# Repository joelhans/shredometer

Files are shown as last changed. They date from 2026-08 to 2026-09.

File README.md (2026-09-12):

# Shredometer

Arduino Nano Every datalogger for a 9-DOF IMU (LSM9DS1), originally written
by Ryan T Cutshall (last updated 17 Sep 2022) for a classic Nano, and later
tuned on real hardware (see "Firmware changes" below). Logs
accelerometer/magnetometer/gyroscope readings to an SD card at high rate and
displays a rolling "shred score" (peak acceleration in g) on a 7-segment LED
display.

## Hardware

- Arduino Nano Every (ATmega4809 — confirmed via `arduino-cli board list`,
  FQBN `arduino:megaavr:nona4809`). Pin-compatible with the classic Nano,
  but a different chip: more flash and RAM, and a different toolchain/core.
- Adafruit LSM9DS1 9-DOF breakout (I2C)
- microSD card module (SPI)
- Adafruit 0.56" 4-digit 7-segment LED backpack (I2C, address `0x70`)
- Momentary push button

### Wiring

| Signal | Nano Every pin |
|---|---|
| SD card CS | D10 |
| SD card MOSI/MISO/SCK | D11/D12/D13 (hardware SPI) |
| Start button | D2 |
| LSM9DS1 SDA/SCL | A4/A5 (hardware I2C) |
| LED backpack SDA/SCL  | A4/A5 (shared I2C bus) |

The button is read with a plain `INPUT` (not `INPUT_PULLUP`), and the code
waits for the pin to go `HIGH` to start logging — so it must be wired with an
external pull-down resistor to GND, with the button connecting the pin to 5V
when pressed.

## Firmware

Sketch: [`Shredometer_Datalogger/Shredometer_Datalogger.ino`](Shredometer_Datalogger/Shredometer_Datalogger.ino)

### Firmware changes

Tuned after testing on the real board:

- Accelerometer range raised from 4G to 16G. At 4G, hard hits clipped at
  the sensor's own ceiling, which capped the shred score below its real
  value. 16G costs some resolution on smaller movements but stops the
  clipping.
- The LED display shows one decimal place below 10g (e.g. `7.3`). At 10g
  and above, it rounds to a whole number instead (e.g. `12`), since the
  display can't fit both an extra digit and the decimal. Clamped at 99.
- The SD file is opened once at the start of a run and kept open, instead
  of being reopened on every sample. It's flushed to the card every 15
  samples. This, combined with raising the serial baud rate below, took
  the sample rate from about 15 Hz to over 100 Hz.
- Serial baud rate raised from 9600 to 115200. At 9600, printing each
  sample line over serial took about as long as the rest of the loop
  combined, and was the main bottleneck. This was the biggest single
  factor in the sample-rate jump above.
- Fixed a bug where every logged line was followed by a blank line in the
  file, caused by a doubled line ending (`println()` on a string that already
  ended in `\n`). **This fix has never reached the board.** Every log through
  DL_61 still ends its lines with `\n\r\n`, which only the old `println()`
  path produces. DL_51 onward runs at 113-117 Hz, so the keep-file-open and
  115200-baud changes from the same commit *are* running — the flashed build
  sits between those edits and this one. Expect the blank lines to disappear
  on the next upload. (They are harmless either way: the analysis script
  skips blank lines.)
- The accelerometer is oversampled and peak-held between logged rows. See
  "Sensor limits" below for why, and "Log format" for the two columns it
  adds.

### Dependencies

Installed via `arduino-cli`:

- `Adafruit LSM9DS1 Library` (pulls in `Adafruit Unified Sensor`, `Adafruit BusIO`, `Adafruit LIS3MDL`)
- `Adafruit GFX Library`
- `Adafruit LED Backpack Library`
- `SD`

### Build environment setup

```sh
sudo pacman -S arduino-cli   # or install per https://arduino.github.io/arduino-cli/latest/installation/
arduino-cli config init
arduino-cli core update-index
arduino-cli core install arduino:megaavr
arduino-cli lib install "Adafruit LSM9DS1 Library" "Adafruit GFX Library" "Adafruit LED Backpack Library"
```

### Compile

```sh
arduino-cli compile --fqbn arduino:megaavr:nona4809 Shredometer_Datalogger
```

Compiling currently reports ~63% flash and ~24% RAM used, leaving about
4.6 KB free for local variables — comfortable headroom on the Nano Every's
ATmega4809. (An earlier revision of this sketch targeted a classic Nano,
which has a third of the flash and RAM; on that chip the same code left
under 100 bytes free, which is why the resource-tightness warning used to
live here. If you're building for a classic Nano, use `arduino:avr:nano`
and `arduino:avr` instead, and budget for that headroom.)

### Upload

Your serial port permissions need to allow access to the board. On Arch,
that means being in the `uucp` group (elsewhere, often `dialout`):

```sh
sudo usermod -aG uucp $USER   # then log out and back in
```

Plug in the board, find its serial port, then:

```sh
arduino-cli board list                 # find the port, e.g. /dev/ttyACM0
arduino-cli upload -p /dev/ttyACM0 --fqbn arduino:megaavr:nona4809 Shredometer_Datalogger
```

### Monitor

```sh
arduino-cli monitor -p /dev/ttyACM0 -c baudrate=115200
```

## Usage

1. Power on. The LED display cycles `2.2:2.2` → `1.1:1.1` → `0.0:0.0` as the
   IMU and SD card initialize.
2. Once at `0.0:0.0`, press the start button to begin logging.
3. Data is written to the next available `DL_N.TXT` file on the SD card
   (`DL_0.TXT`, `DL_1.TXT`, ...), as CSV with a header row.
4. The display shows `instantaneous shred score : max shred score` (in g),
   updated every 15 samples. Below 10g, each side shows one decimal place
   (e.g. `7.3`). At 10g and above, that side shows a whole number instead
   (e.g. `12`), since the display can't fit both an extra digit and the
   decimal.

## Analyzing logs

`scripts/analyze_log.py` parses a `DL_N.TXT` file and prints summary stats
(sample count, duration, sample rate, peak/mean shred score). It skips rows
damaged by a bad SD write (a run of `0xFF` mid-line) and reports how many it
dropped; `DL_61.TXT` contains one such row.

```sh
python3 -m venv .venv
.venv/bin/pip install -r scripts/requirements.txt
.venv/bin/python scripts/analyze_log.py path/to/DL_0.TXT
```

It can also produce output in two formats:

- `-o plot.png` — a static matplotlib plot of acceleration and shred score.
- `-H report.html` — a self-contained, interactive HTML report (open it in
  any browser, no server needed): acceleration and shred-score charts with
  hover tooltips, drag-to-zoom, a per-axis legend, and a per-minute data
  table. Uses `scripts/report_template.html` as its template.

```sh
.venv/bin/python scripts/analyze_log.py path/to/DL_0.TXT -H report.html
```

Pass `--accel-range` to set where the accelerometer saturates, in g. It
controls the report's clipping detection and the reference line on the
shred-score chart.

The default is `24`, which looks wrong next to the firmware's
`LSM9DS1_ACCELRANGE_16G` but is correct. The LSM9DS1's "±16 g" mode has a
sensitivity of 0.732 mg/LSB, and a full-scale int16 reading of 32767 counts
is therefore 23.99 g, not 16 g. The Adafruit library scales by 9.80665, so
the rail lands at 235.20 m/s², which this script's `G = 9.8` turns into
exactly 24.0000 g. The datasheet's range label and its sensitivity constant
disagree; the sensitivity is what the hardware does. DL_61 confirms it: 61
samples sit on 235.20 m/s² and nothing goes past it.

Use `--accel-range 6` for any log captured before the 16G change (the same
1.5x applies to the "±4 g" setting).

Two things follow from this that are easy to get wrong when reading a report:

- The rail is **per axis**. The shred score is a 3-axis magnitude, so it can
  legitimately reach √3 × 24 = 41.6 g with no axis railing. A shred score
  above 24 g is not by itself evidence of clipping.
- A sample with an axis on the rail was truncated, so its shred score is a
  lower bound, not a measurement. In DL_61 that includes the headline 35.07 g
  peak, and 20 of the top 30 hits.

## Questions to ask and answer

- What's the "correct" ceiling to set? The LSM9DS1 has no range above the
  one we're already using, and DL_61 railed 61 times against DL_55's 2, so
  answering this probably means a different accelerometer. See "Sensor
  limits" below.
- Does not having the Shredometer _firmly_ mounted to the bike have an impact on
  the data? If it's on there really firmly, do we get "cleaner" data?
- Does the starting angle of the Shredometer have any impact on the data? Right
  now it's sitting at an angle because it's attached to the downtube like a
  water bottle might be.
- Does the positioning of the accelerometer on the bike have an impact on the
  data? What if I put it on the rear triangle, which has all the suspension
  motion?
- Do we need any kind of calibration? At the start of a session? Based on
  anything the rider is doing?

## Sensor limits

Two separate ceilings constrain the data, and they are easy to confuse.

### 1. Amplitude: the 24 g per-axis rail

Covered under "Analyzing logs" above. DL_61 railed 61 times; DL_55 railed
twice. The tail of the unrailed distribution falls off by a factor of e
every ~3.5 g, so clearing DL_61 entirely would need roughly
24 + 3.5 x ln(61) = **~38 g**. A ±50 g or ±100 g part would leave margin for
a harder ride. The LSM9DS1 has nothing above the range we already use, so
this means a different accelerometer (the usual shock-logging parts are the
ADXL375 at ±200 g or the H3LIS331DL at ±100/200/400 g).

### 2. Bandwidth: we are aliasing, and this is the bigger problem

The accelerometer's real output data rate is **952 Hz**, with a 408 Hz
anti-aliasing filter. We poll it at 113 Hz. Nyquist is 56.6 Hz, so
everything between 56.6 Hz and 408 Hz folds back down into the measurement.

This is not obvious from the sketch. `setupSensor()` calls
`lsm.setupAccel(lsm.LSM9DS1_ACCELRANGE_16G)` with one argument, and the
library's second parameter defaults to `LSM9DS1_ACCELDATARATE_10HZ` — so the
code appears to ask for 10 Hz. It does not get it. On the LSM9DS1, whenever
the gyroscope is powered on, the accelerometer ODR is dictated by `ODR_G` in
`CTRL_REG1_G` and the `ODR_XL` bits are ignored. `begin()` writes
`CTRL_REG1_G = 0xC0`, which is 952 Hz. The log confirms this: no two
consecutive accelerometer readings in DL_61 are identical, which could not
happen at a 10 Hz ODR polled at 113 Hz.

The aliasing shows up in the spectrum. Accelerometer power does not roll off
toward Nyquist the way a band-limited signal must — the 40-56.6 Hz band still
holds 29% as much power as the entire 0-10 Hz band. That energy is folded in
from above.

The practical consequence: **a recorded peak is not a repeatable measurement
of an impact.** A frame hit rings in the hundreds of Hz. What we log is
whatever the ring happened to be at the instant we polled. Two identical hits
will produce different numbers. Raising the range without fixing this gives
bigger numbers that are still not reproducible.

### What the firmware now does about it (not yet flashed)

The sketch oversamples. `loop()` reads only the accelerometer as fast as the
bus allows, tracks the largest magnitude it sees, and writes a row every
`LOG_INTERVAL_MS` (8 ms, so ~125 Hz). The row carries both the single
instantaneous reading it always did *and* the peak across the burst.

Three supporting changes went with it:

- I2C now runs at 400 kHz instead of 100 kHz, which fits about four times as
  many reads into each window.
- `setupAccel()` states the 952 Hz data rate explicitly. This changes no
  behavior — `ODR_G` already governed it — but the call no longer reads as
  though it asks for 10 Hz.
- The LED display's shred score comes from the burst peak rather than one
  instantaneous sample, so it shows the hardest hit in the window.

### 3. The I2C bus is the real bottleneck (measured on hardware)

An on-board diagnostic settled how much the oversampling actually buys. At the
current 100 kHz bus speed:

| Measurement | Value |
|---|---|
| One `readAccel()` | **946 us** |
| One logged row, no SD write | 6.5 ms |
| One logged row, with SD (from the 113 Hz in real logs) | ~8.8 ms |
| Spare time in an 8 ms window | ~1.5 ms |
| Extra oversampled reads that fit | **1** |

A new sensor sample arrives every 1050 us at 952 Hz, and a single read costs
946 us. **At 100 kHz the bus can barely move one sample in the time the sensor
produces one**, and the per-row work consumes the window on its own. Six bytes
per sample at 952 Hz is 5.7 kB/s, against roughly 5.5 kB/s of usable 100 kHz
I2C throughput. We are at the wire's limit, not the sensor's.

So the oversampling as it stands gains about one extra reading per row. It is
kept because it is correct and becomes valuable the moment the bus is faster,
but it does not fix the peaks by itself.

**400 kHz is not available on this wiring.** It hung the bus on two separate
runs: the first `readAccel()` after `Wire.setClock(400000)` never returns, and
only a power cycle clears it.

The cause is almost certainly the cable to the bar-mounted display. That cable
puts the LED backpack on the far end of roughly a metre of wire, and its
capacitance sits across the same bus the accelerometer uses. Fast mode allows
a 300 ns rise time; with the two breakouts' pull-ups in parallel (about 5k)
the bus does not meet it:

| Bus capacitance | Pull-ups 5k | Pull-ups 2.2k |
|---|---|---|
| 60 pF (bench wiring only) | 254 ns — OK | 112 ns — OK |
| 100 pF (~0.7 m to the bars) | **424 ns — over** | 186 ns — OK |
| 150 pF (~1.2 m to the bars) | **635 ns — over** | 280 ns — OK |

So 400 kHz is not out of reach: it needs 2.2k pull-ups, which is a one-dollar
fix. Note that this stops mattering once the accelerometer moves to SPI, since
the I2C bus would then carry only the display, which updates a few times a
second and does not care about bus speed.
The sketch no longer sets 400 kHz.

Note that a wedged bus *can* be cleared in software, without a power cycle:
clock SCL up to 16 times until the stuck slave releases SDA, then issue a
manual STOP. The diagnostic does this at startup and recovers reliably. Worth
adding to the datalogger if the bus ever wedges during a ride.

**What this means for the FIFO.** Draining 32 FIFO samples is 192 bytes, which
at 100 kHz takes about 17 ms — longer than the logging window it is meant to
fill. The FIFO does not help until the bus is faster. Raising the bus speed
(or moving the accelerometer to SPI) comes first; the FIFO comes after.

Do all of this before buying a new accelerometer. It is the cheap experiment,
and it sizes the amplitude problem properly: with a real peak-hold the 24 g
rail will be hit far more often than 61 times, which is what tells us how
much range we actually need.

## Log format

Rows are CSV with a header. The first ten columns are unchanged from earlier
logs, so old files and new ones parse the same way:

| Column | Meaning |
|---|---|
| `Time Elapsed (ms)` | milliseconds since logging started |
| `Accel X/Y/Z (m/s^2)` | one instantaneous reading, as before |
| `Mag X/Y/Z (uT)` | magnetometer |
| `Gyro X/Y/Z (rad/s)` | gyroscope |
| `Peak \|a\| (m/s^2)` | **new** — largest acceleration magnitude across every oversampled read since the previous row |
| `Burst Samples` | **new** — how many reads that peak covers |

Keep the instantaneous columns for anything distributional: means, spectra,
and orientation all stay valid, and they stay comparable with DL_46 through
DL_61. Use `Peak |a|` for anything about impacts.

`scripts/analyze_log.py` does not read the two new columns yet. It still
computes the shred score from the instantaneous accelerometer columns, so it
runs unchanged on both old and new logs. Switching the shred score over to
`Peak |a|` is a small change, but it would make new reports incomparable with
the existing ones, so it should wait until there is a log to test it against.

## Mk2

The next version replaces the Nano Every and the LSM9DS1 with a XIAO
nRF52840 Sense and an ADXL375 (±200 g, SPI), logs binary at 1 kHz, and puts
the electronics in a printed case that bolts straight to the bottle bosses.
The staged plan, bill of materials, vendor list, and open decisions are in
[docs/mk2.md](docs/mk2.md). Parts are ordered as of 2026-09-07.

## To build

- A snap-in cage that mounts to standard water bottle mounts. The current
  attempt is `hardware/bottle_cage_mount.scad` (v2 cradle, unproven on a
  print). Mk2 replaces it with a case that is its own mount; see
  [docs/mk2.md](docs/mk2.md).
- A handlebar mount for the screen.

## To do

- **Teach `analyze_log.py` about `Peak |a|`.** The firmware now logs a
  peak-held magnitude per row (see "Log format"), and the script still
  ignores it: the shred score comes from the instantaneous accelerometer
  columns. Switching over would make peaks meaningful, but it also makes new
  reports incomparable with DL_46 through DL_61, so it needs a deliberate
  choice: either a `--peak` flag, or report both series side by side. Wait
  for a log that actually has the column before doing it.
- **Get the accelerometer off the shared 100 kHz I2C bus.** This is the
  binding constraint on data quality (see "Sensor limits"). Either fix the
  pull-ups so 400 kHz is stable, or put the accelerometer on SPI. The FIFO
  and any higher-range sensor both depend on this being solved first.
- **Uploads need `pyserial`, not `arduino-cli monitor`.** Reading this board's
  serial output requires DTR asserted. `arduino-cli monitor` and `cat
  /dev/ttyACM0` both return nothing; a short pyserial script works. Note also
  that `avrdude` prints `jtagmkII_initialize(): Cannot locate "flash" and
  "boot" memories in description` on every upload. It is harmless — the flash
  write completes and reports its byte count.

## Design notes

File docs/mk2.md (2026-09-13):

# Shredometer Mk2

A staged plan for rebuilding the logger around a sensor that can see the
real hits, on a bus fast enough to carry them, in a case that is its own
bottle mount.

Written 2026-08-30 from DL_55, DL_61, and on-board timing. Originally a
Claude artifact:
https://claude.ai/code/artifact/996e3555-30bf-40b6-853d-b44880566f15.
This file is the copy of record. Update it here.

Status (2026-09-13): all Phase 2 parts are on hand and wired up through
the display; the bench log in [mk2_build.md](mk2_build.md) has every
result. The logger firmware is written: `Shredometer_Mk2/`, plus
`scripts/mk2_to_csv.py` to convert its binary log into the CSV the
existing analysis reads. The bring-up sketch stays in
`Shredometer_Mk2_Bringup/` for wiring a new subsystem. Not yet run on
real hardware end to end (SD write path only exercised via bring-up, not
the logger). The first ride does not need the display: the plan is to
power the logger from the switch alone and mount it on the bike as-is
inside foam packing in the Mk1 box, ahead of the real Mk2 case. No Mk2
CAD yet; `hardware/` still holds the v2 cradle for the current enclosure,
which Mk2 replaces.

## Why a rebuild, not a part swap

Three ceilings, and they are coupled:

1. **Amplitude.** The LSM9DS1 rails at 24 g. DL_61 hit that 61 times, and
   20 of its top 30 hits are floors, not measurements. The LSM9DS1 has no
   higher range.
2. **Bus.** One `readAccel()` costs 946 µs on the 100 kHz I2C bus. A new
   sample arrives every 1050 µs. 400 kHz wedges the bus, almost certainly
   because of the cable to the bar display (see "Sensor limits" in the
   README).
3. **Bandwidth.** Logging at 113 Hz against a 408 Hz sensor bandwidth
   aliases ring-down into the data. Peaks are not repeatable.

A bigger sensor on the same bus gives the same aliasing at coarser
resolution. The size problem is downstream of this: the enclosure is
99 x 55 x 43 mm because it houses a Nano Every plus three breakouts and
their wiring. The electronics want about 40 x 25 mm.

The mount is the other reason. The v1 cradle failed on its first ride, and
v2 is four printed parts, eight screws, and four foam pads whose only job is
to grip a box that was never designed to be gripped. If the case is the
mount, none of that has to exist.

## Phases

Each phase is useful on its own. Do them in order: each answers a question
the next depends on.

### Phase 1: prove the sensor

Wire an ADXL375 breakout to the existing Nano Every over SPI, alongside the
existing hardware. Ride once. Look at the peaks.

- **Answers:** how hard the bike actually hits. The 38 g figure in the
  README is an extrapolation from clipped, aliased data.
- **Why SPI:** the I2C bus is saturated. The SD card is already on SPI; the
  ADXL375 needs only its own chip-select pin.
- **Also try:** 2.2k pull-ups on SDA and SCL, then retry 400 kHz. The two
  breakouts' pull-ups in parallel are about 5k, which across a metre of
  cable gives roughly a 424 ns rise time. Fast mode allows 300 ns. At 2.2k
  the bus lands near 186 ns.
- **If you stop here:** you know the range to specify, and you have a
  working high-g logger in the old box.

### Phase 2: prove the architecture

Replace the Nano Every with a XIAO nRF52840 Sense, switch the log format
from CSV to binary, and target 1 kHz logging. Confirm the rate with the
burst counter already in the firmware. The display stays wired as it is.

- **Why nRF52840, not RP2040:** wireless is planned for Phase 3, so pick
  the radio-capable part now and port the firmware once. 64 MHz over SPI
  covers 1 kHz logging with room to spare. It also has onboard LiPo
  charging.
- **Why Sense:** the Sense variant has a 6-axis IMU onboard, which covers
  the gyro at no extra part. No magnetometer, which nothing uses.
- **Why binary:** a CSV row is about 65 bytes. Three `int16` values plus a
  timestamp is 8 to 10. Eight times the rate for the same file size.
- **Proves:** that aliasing is gone. Sample above about 800 Hz and the
  folding stops.
- **Bench build:** hand-wired on a 5 x 7 cm FR4 protoboard. Its layout sets
  the post positions and cavity for the Phase 4 case, so build this before
  designing the case.
- **If you stop here:** the data is valid. Correct amplitude, no aliasing.
  Everything after is size and convenience.

### Phase 3: carrier PCB and the radio link

A small board (about 40 x 25 mm) with footprints for the breakouts, not
bare chips. KiCad, JLCPCB or PCBWay or OSH Park, order five.

- **Cutting the cable means a second device.** The bar end needs its own
  MCU, cell, charging, enclosure, firmware, and a reconnect story. That is
  the real cost of wireless, not the radio.
- **Sequence:** logger board first. Leave the bar end as a hand-wired plain
  XIAO nRF52840 plus the existing HT16K33 display for a while.
- **Why BLE:** it is what the nRF52840 is built for, and a phone can talk
  to the logger too.

### Phase 4: case as mount

One printed body with the bottle-boss bolt pattern through it, and a
bolt-on lid. The spine, both collars, the separate lid, and the foam pads
stop existing.

- **Governing constraint:** 64 mm bolt spacing. The body spans both bosses,
  so it lands near 85 mm long. Target about 85 x 35 x 20 mm, one body plus
  one lid, about 60 cm³ against the current 234 cm³.
- **Carries over from `hardware/bottle_cage_mount.scad`:** the M5
  counterbore geometry, the captive M3 nut scheme for the lid, and the
  print-orientation and volume-intersection checks.
- **Structure:** boards on printed posts inside a rigid body. No sliding
  fit, no `FIT_CLEARANCE`, no foam. Foam was a mechanical filter with an
  uncharacterised transfer function, so removing it also removes an
  unknown from the data.
- **Bolt heads:** recess both M5 heads into the floor inside the body. Bolt
  the empty body to the frame, fit the electronics, close the lid.
- **Sealing:** a gasket (silicone sheet or O-ring cord, 1 to 2 mm) at the
  lid. Readout over USB-C, so the bottom face is solid and there is no SD
  hatch facing road spray.
- **Cable exit:** the display is wired until Phase 3, so the body needs one
  sealed exit (4-pin connector or gland) until then. After Phase 3 it has
  none.
- **Fasteners:** two M5 bottle bolts, four M3x10 lid screws with captive
  nuts. Down from twelve.
- **Hard mounting changes the data.** A rigidly mounted sensor sees more
  high-frequency content than the foam-cradled one did. Note the change in
  the log naming so Mk1 and Mk2 rides are not compared blindly.

## Bill of materials

Prices are approximate US retail as of 2026-08-30.

| Part | Why this one | Phase | Qty | ~USD |
|---|---|---|---|---|
| ADXL375 breakout, Adafruit 5374, ±200 g | Purpose-built shock sensor. 3200 Hz output, SPI and I2C. 25.5 x 17.8 mm. Buy genuine: a relabelled ADXL345 gives ±16 g and nothing in the data would tell you. | 1 | 1 | 13 |
| Jumper wires + protoboard, FR4, plated holes, 0.1" pitch | Female-female jumpers plus 28 AWG silicone stranded wire. Assorted pack (2x8 through 5x7 cm); use the 5x7 for Phase 2. Avoid phenolic board. | 1 | 1 | 8 |
| 2.2k resistors | I2C pull-ups, the one-dollar 400 kHz fix. | 1 | 2 | 1 |
| XIAO nRF52840 Sense | 21 x 17.5 mm, BLE, USB-C, onboard 6-axis IMU, LiPo charging, castellated pads. | 2 | 1 | 18 |
| microSD breakout, SPI, 3 V logic | Capacity. Replace with a bare push-push socket on the Phase 3 board. | 2 | 1 | 8 |
| LiPo cell, 500 to 1000 mAh, about 30 x 20 x 6 mm | With protection circuit and JST fitted. Not a bare pouch cell. | 2 | 1 | 9 |
| Tactile button + slide switch | Start and power. Wire the button to `INPUT_PULLUP`; the current external pull-down is unnecessary. | 2 | 2 | 2 |
| Resistors and capacitors: 2.2k, 0.1 µF, 10 µF | Pull-ups and decoupling near every module. | 2 | - | 6 |
| I2C level shifter, BSS138, 4-channel (Adafruit 757) | The bar display runs at 5 V; the XIAO at 3.3 V. Required once the display is on the boost. | 2 | 1 | 4 |
| 5 V boost converter (Adafruit MiniBoost 4654) | Required, not optional: the display's LED current through the XIAO's 3.3 V regulator corrupts the ADXL375 (see the bench log). Runs the display from the battery. | 2 | 1 | 5 |
| 100 µF electrolytic capacitors, 6.3 V or more | One at the backpack's power pins, one at the boost input. | 2 | 2 | 1 |
| Second XIAO nRF52840, plain | The bar end's brain once the cable goes. | 3 | 1 | 16 |
| Second LiPo cell | Bar end. 50 to 90 mA with the display lit, so 500 mAh is several rides. | 3 | 1 | 9 |
| Custom PCB, 5 pcs | Boards are about $5; shipping is most of it. | 3 | 5 | 25 |
| 4-pin connector + cable gland, JST-GH or similar | Only if the case is built before the cable goes. | 4, maybe | 1 | 6 |
| Silicone gasket sheet or O-ring cord, 1 to 2 mm | Seals the lid. | 4 | 1 | 8 |
| M5 bottle bolts + washers | Already measured. | 4 | 2 | 3 |
| M3x10 socket screws + nuts | Same captive-nut scheme as the v2 cradle. Already owned. | 4 | 4 | - |

Totals: Phase 1 about $22. Phases 1 and 2 core parts about $65. All
phases, optionals excluded, about $126.

### Module footprints (datasheet values, unverified with calipers)

| Module | Size |
|---|---|
| XIAO nRF52840 Sense | 21 x 17.5 mm |
| ADXL375 breakout | 25.5 x 17.8 mm |
| microSD breakout | about 25 x 24 mm |
| LiPo | about 30 x 20 x 6 mm |
| 5 x 7 cm protoboard | 50 x 70 mm, about 19 x 27 holes |

Measure every one of these before sizing the Phase 4 case. Do not design
fits from this table.

## Where to buy

Shop by vendor, not by search engine.

| What | Where | Why there |
|---|---|---|
| ADXL375 breakout | Adafruit 5374. Also Pimoroni, Jameco, Digi-Key, Mouser. | Genuine part matters. |
| XIAO nRF52840 Sense | seeedstudio.com direct. Also Amazon, Newegg. | Seeed ships from CN, US, and DE warehouses. Pick the local one. |
| microSD breakout, level shifter, 5 V boost | Adafruit or SparkFun | Documented boards, libraries the examples assume. |
| LiPo cells | Adafruit or SparkFun | Protection circuit and JST fitted. |
| Passives, connectors, exact values | Digi-Key or Mouser | Real stock numbers, no counterfeits. |
| Protoboard, hookup wire, assortments | Amazon | A resistor is a resistor. |
| Soldering iron, multimeter | Amazon, or Pine64 direct for a Pinecil | Buy on reviews. |
| M3 and M5 fasteners, gasket sheet | McMaster-Carr, or Amazon assortments | McMaster tells you exactly what you get. |
| PCB fabrication | JLCPCB, PCBWay, OSH Park | Upload Gerbers from KiCad. |

## Tools

| Item | Needed for | Notes | ~USD |
|---|---|---|---|
| Temperature-controlled soldering iron (e.g. Pinecil) | Phase 2 on | The single most important purchase. | 40 |
| Solder, flux pen, desoldering wick | Phase 2 on | Leaded 63/37 is easier to learn on. Flux matters more than technique. | 20 |
| Multimeter | Phase 1 on | Continuity beeper is 90% of its use. | 25 |
| Flush cutters, tweezers, helping hands | Phase 2 on | The vise matters more than it sounds. | 30 |
| 3D printer | Phase 4 | Already owned. | - |
| KiCad, OpenSCAD, arduino-cli | Phases 3 and 4 | All free. | - |

What is genuinely hard, ranked: PCB design (the only new discipline), the
firmware port to the nRF52840 (moderate: SPI setup and the binary format
are new), soldering castellated modules (easier than it looks with flux),
the enclosure (easiest, the hard constraints are already solved).

Deliberately out of scope: bare surface-mount chips, hot-air rework, paid
assembly. Not worth it until the Phase 3 board works.

## Decisions

- **Display: wired now, BLE at Phase 3.** Decided. Once the accelerometer
  moves to SPI, the I2C bus carries only the display, and a slow bus down a
  long cable is fine for a few updates a second. Test the HT16K33 backpack
  at 3.3 V first. If it is too dim in daylight, add the boost and level
  shifter.
- **Storage: keep microSD, read it over USB-C.** The nRF52840 can present
  the card as a USB drive. No card removal, no hatch. Costs firmware work.
- **Gyro and magnetometer:** the Sense Plus's onboard IMU gives the gyro
  for free, with one catch: its power pin must be driven in high-drive
  mode or the IMU never powers up. See the bench log in
  [mk2_build.md](mk2_build.md). The magnetometer goes away; nothing used
  it.
- **Open:** whether the bar end ever gets its own PCB or stays a hand-wired
  XIAO in a printed box. Live with it before deciding.
- **Open:** the Phase 2 protoboard layout. This gates the Phase 4 case.
- **Open:** peak detection on the ADXL375. At 49 mg per count and 3200 Hz
  bandwidth the resting noise is about 0.2 g rms per axis, so the largest
  of 6300 raw samples a second sits near 2.5 g. The logger cannot report
  raw single-sample peaks. Choose between a lower output data rate (each
  halving cuts noise by about 1.4), a short moving average, or both, and
  verify with a tap test. Also trim the zero-g offset (six-position)
  before trusting anything below a few g.

## Next

1. Parts arrive. Measure every module with calipers and update the
   footprint table above.
2. Phase 1: ADXL375 on the Nano Every over SPI, plus the 2.2k pull-up
   test. One ride.
3. Phase 2: port the firmware to the XIAO, binary log, 1 kHz. Build it on
   the 5 x 7 cm protoboard.
4. Flash `Shredometer_Mk2` to the perfboard XIAO and confirm a full
   power-on-to-power-off log cycle: file created, sectors written, file
   closed cleanly. Pull the card and run `scripts/mk2_to_csv.py` on it.
5. First ride with the perfboard packed in the old enclosure, no display,
   no button: switch on, ride, switch off. This is the check that the
   architecture works end to end before committing to Phase 4 CAD.
6. Phase 4 CAD: a new parametric SCAD file for the body and lid, sized to
   the real protoboard, measured with calipers. Reuse the bolt interface
   and the nut scheme from `hardware/bottle_cage_mount.scad`.

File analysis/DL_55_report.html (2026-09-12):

Shredometer datalogger ·

# Ride Report

Duration

Samples

Peak shred score

Sensor range

## Acceleration

X / Y / Z, in m/s². Band is the range within each window, line is the mean.

X Y Z

Drag on the shred-score chart below to zoom into a time range — both charts stay in sync.

## Shred score

Acceleration magnitude in g. Peak line matches what the onboard display shows; thin line is the window mean.

Peak Mean

Reset zoom

Accel X

Accel Y

Accel Z

Shred peak

Shred mean

Show data table

Time | Samples | Mean accel (m/s²) | Mean shred (g) | Peak shred (g)

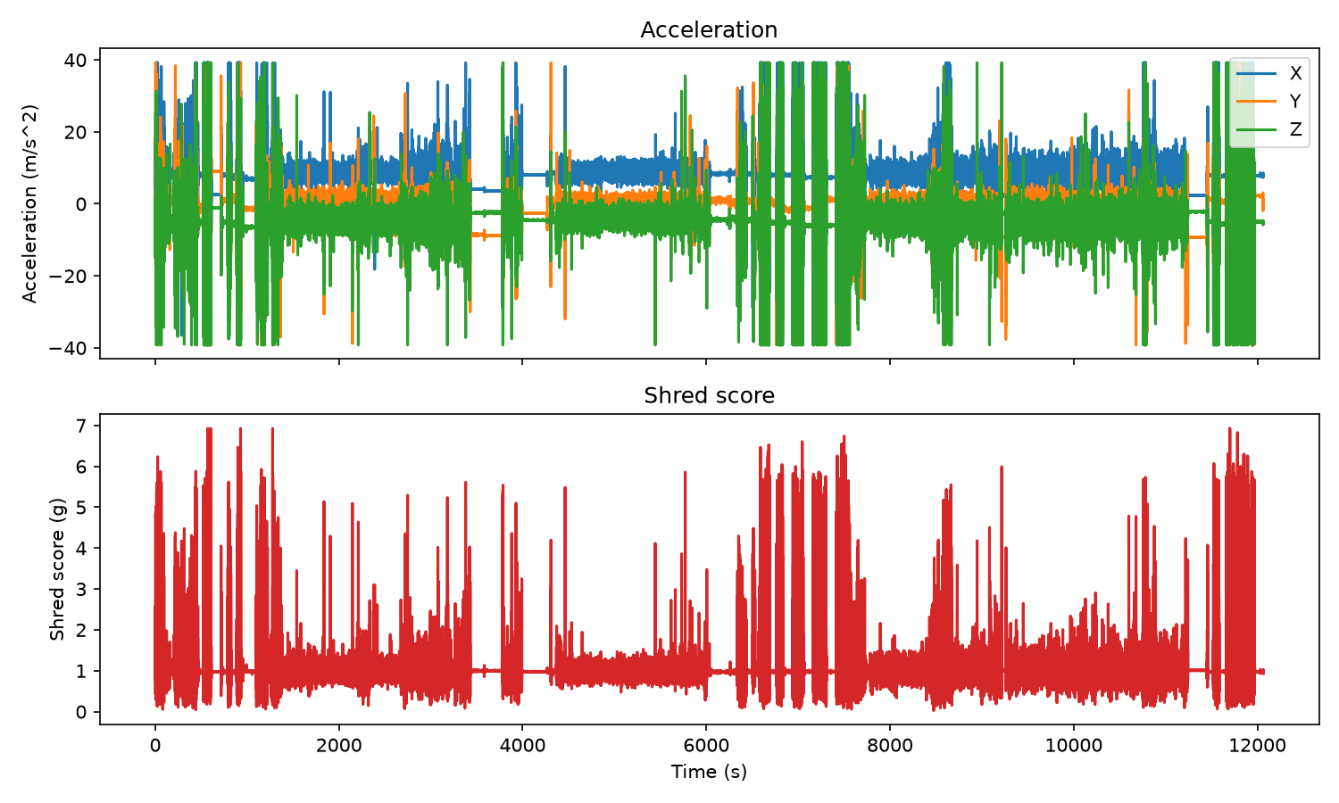
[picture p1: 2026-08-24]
analysis/DL_46_plot.png

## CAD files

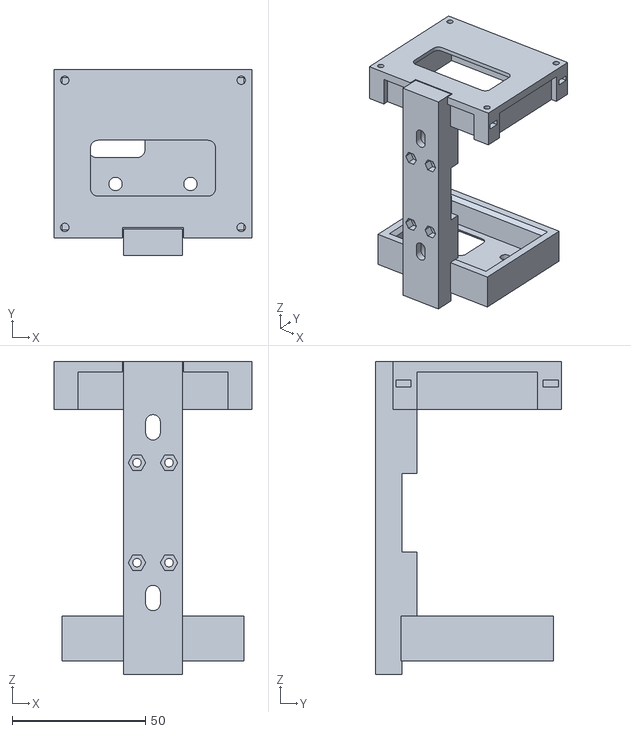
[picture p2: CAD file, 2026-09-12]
hardware/cage_full_REFERENCE_ONLY.stl
74.2 x 69.7 x 117.4

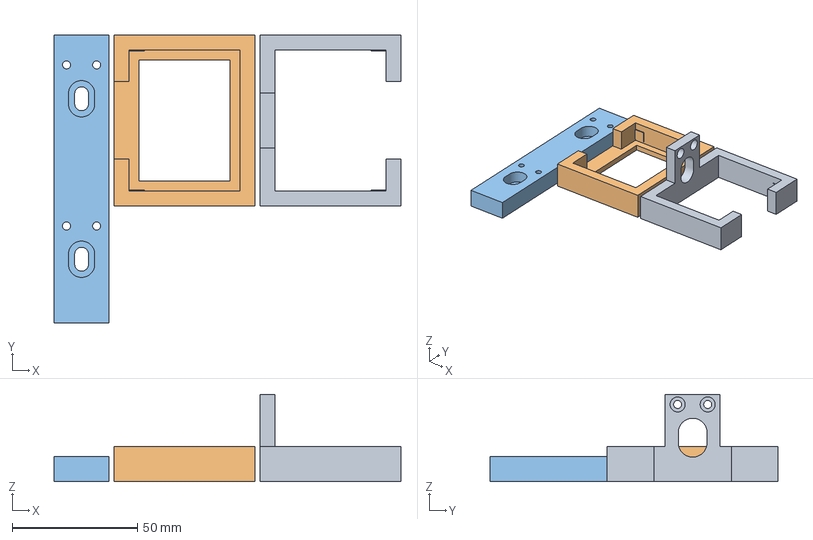
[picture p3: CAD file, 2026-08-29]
hardware/full-print.3mf
138.4 x 115.0 x 34.8 mm
cradle_top_test.stl
cradle_bottom_test.stl
mount_test.stl

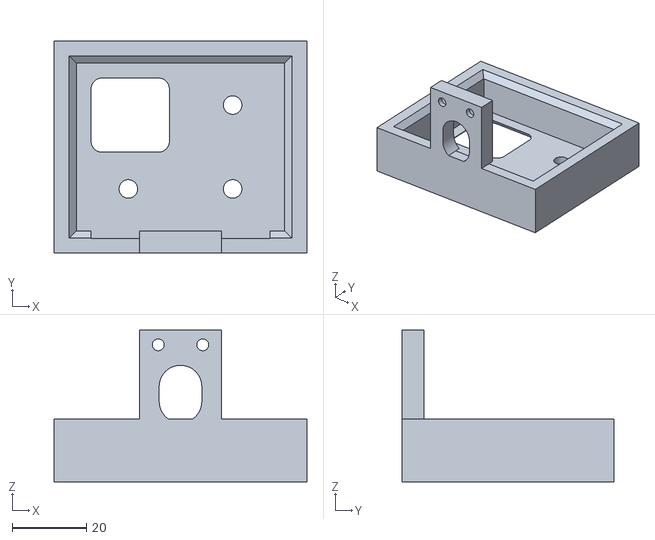
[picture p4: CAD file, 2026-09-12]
hardware/cradle_bottom_test.stl
68.2 x 57.2 x 41.0

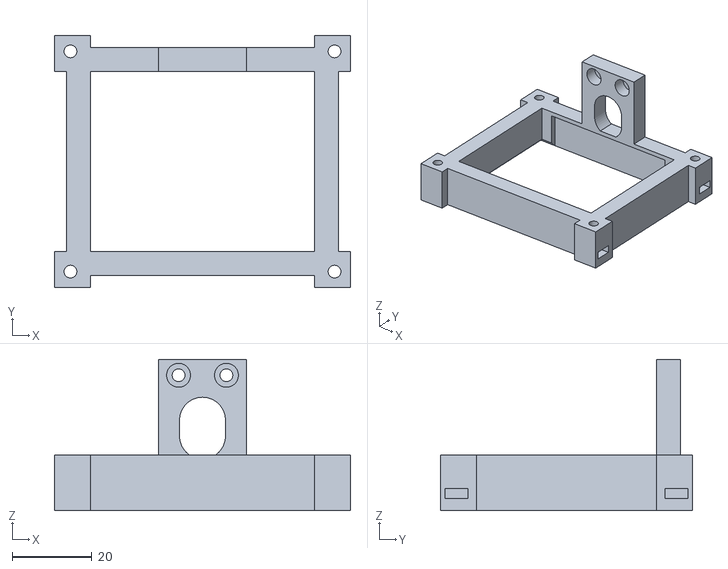
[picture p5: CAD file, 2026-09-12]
hardware/cradle_top_test.stl
74.2 x 63.2 x 38.0

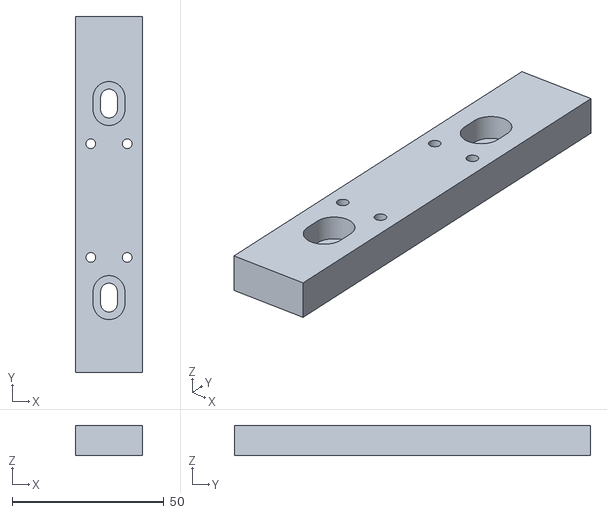
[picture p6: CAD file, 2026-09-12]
hardware/mount_test.stl
22.0 x 117.4 x 10.0

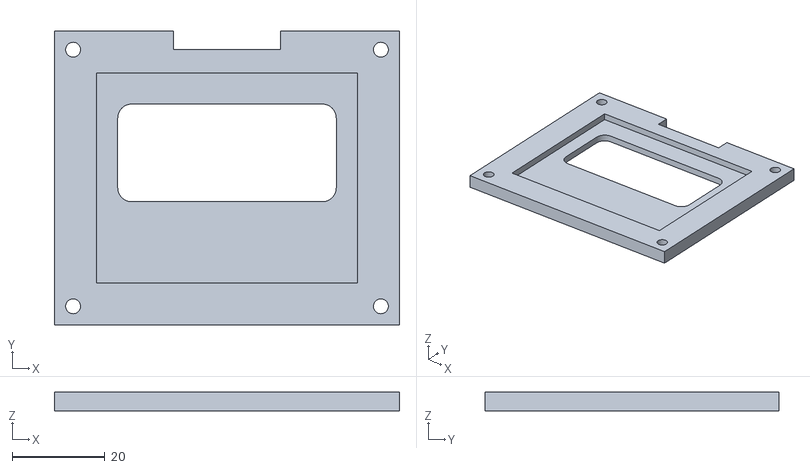
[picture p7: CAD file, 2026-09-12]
hardware/lid_test.stl
74.2 x 63.2 x 4.00

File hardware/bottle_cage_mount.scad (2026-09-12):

// ============================================================
// Shredometer bottle-cage mount + cradle
// ============================================================
// STATUS (2026-09-07): this is the Mk1 cradle, for the bought
// 99 x 55 x 43 mm enclosure. Mk2 replaces the cradle with a printed
// case that is its own bottle mount; see docs/mk2.md. What carries
// over from here: the M5 bolt interface (spine section), the captive
// M3 nut scheme (lid section), and the print-orientation and
// volume-intersection checks described below.
//
// Four printed parts:
//
//   spine         -- baseplate, bolts to the frame's 2-bolt water-
//                    bottle boss.
//   bottom cradle -- a closed collar with a solid floor. The
//                    enclosure stands on a foam pad here.
//   top cradle    -- a closed collar, open at the top.
//   lid           -- a flat plate that bolts onto the top cradle.
//                    This is the "roof": with a foam pad under it,
//                    it traps the enclosure vertically.
//
// The SD card sits on the enclosure's bottom face and has to come out
// after every ride, so the bottom collar's floor opens under the card
// slot. See "SD card access" below. Nothing has to be unbolted to read
// the card, which is also why the lid's screws thread into captive
// nuts rather than into the plastic.
//
// ---------------- What changed after the first ride ----------------
// The first version held the enclosure with friction alone: each
// collar was a "C" with an open front and a small inward pinch, and
// the top collar was open at both ends. On a real ride the enclosure
// worked its way up and out. Three changes fix that:
//
//   1. Both collars are now closed rings. No front opening, no pinch
//      bump, no window through either wall. A closed ring is far
//      stiffer than a "C" and it cannot spread open over a bump.
//   2. The top collar gets a bolt-on lid. The enclosure is now
//      captured between two foam pads (floor and lid) with a fixed
//      amount of crush, so it has nowhere to travel vertically.
//   3. Foam pads take up every remaining gap. See "Foam" below.
//
// A closed 6mm-wall ring cannot be flexed open to admit the
// enclosure, so the enclosure no longer goes in from the front. It
// drops straight down through the top collar into the bottom one,
// and the lid goes on last. Both collars share the same cavity, on
// the same axis, so this is one straight slide.
//
// ---------------- Foam ----------------
// 5mm firm closed-cell sheet, no adhesive backing, so every pad
// needs geometry to hold it in place:
//
//   floor pad -- lies on the bottom collar's solid floor. The cavity
//                walls box it in on all four sides.
//   lid pad   -- sits in a shallow pocket in the lid's underside.
//   back pads -- one per collar, in a shallow pocket milled into the
//                back wall (the spine side). Each pocket is closed at
//                the bottom, so insertion drag pushes the pad down
//                onto a ledge instead of dragging it out.
//
// Cut every pad about 1mm oversize in width and height and press it
// in. The pocket depth means only part of each pad's thickness
// stands proud, which keeps the cradle close to its old size.
//
// Foam only has to sit on one face of an axis to stop a rattle: it
// presses the enclosure against the opposite hard wall, and a
// preloaded contact does not buzz. So the back pads alone handle
// front-to-back. Side to side stays a plain sliding clearance.
//
// ---------------- Assembly order ----------------
// The ring-to-spine screws go in from inside, so they must be driven
// before the enclosure goes in. Both collars now hang off a brace
// that puts its screws in open air between the collars, clear of the
// closed walls, so a driver still reaches them.
//
//   1. Press an M3 nut into each of the four pockets on the spine's
//      back face, and one into each of the top collar's four corner
//      slots.
//   2. Bolt both collars to the spine (M3 cap screws, from inside).
//   3. Bolt the spine to the frame. Both M5 bolts sit between the
//      collars; each brace has a window over its own bolt.
//   4. Press the foam pads in: floor, both back pads, lid.
//   5. Slide the enclosure down through the top collar until it
//      rests on the floor pad.
//   6. Bolt the lid on, into the four corner nuts.
//
// Hardware: 8x M3x10 socket-head cap screws, 8x M3 nuts, plus the two
// M5 bottle-cage bolts. Every screw is the same length on purpose.
//
// ---------------- Print order ----------------
//   RENDER = "mount"         -> the spine, laid on its long face.
//   RENDER = "cradle_bottom" -> the bottom collar, upright.
//   RENDER = "cradle_top"    -> the top collar, upside down.
//   RENDER = "lid"           -> the lid, upside down.
//   RENDER = "full"          -> the whole cage, for preview only.
//
// Print one collar first and check that the enclosure slides through
// it with the back pad in. That is the only fit left to dial in, and
// FIT_CLEARANCE is the knob.

// ---------------- Shredometer enclosure (measured) ----------------
ENCL_LEN   = 99;   // long axis -- mounts vertically, like a bottle
ENCL_DEPTH = 43;   // front-to-back (against the frame)
ENCL_WIDTH = 55;   // side-to-side

// ---------------- Fit ----------------
// Side-to-side only. Front-to-back is set by the back foam pad, and
// vertical by the floor and lid pads, so neither uses this.
// The enclosure now slides the full length of the top collar, so
// this is a sliding clearance, not a press fit -- if it binds,
// raise it; if it rocks side to side, lower it.
FIT_CLEARANCE = 0.6;

// ---------------- Foam ----------------
FOAM_THICK          = 5;   // free thickness of the sheet
FOAM_V_CRUSH        = 0.8; // designed squash per pad, floor and lid.
                            // The lid bottoms out on the collar's top
                            // face, so this is a hard stop: it cannot
                            // be over-tightened, and it does not drift.
FOAM_BACK_CRUSH     = 0.8; // designed squash of each back pad
FOAM_POCKET_DEPTH   = 2;   // how far the back and lid pads sink into
                            // their pockets, so less of the pad stands
                            // proud and the cradle stays compact
FOAM_PAD_SIDE_MARGIN = 4;  // wall left on each side of a back pocket
BACK_PAD_LEDGE      = 1.5; // un-pocketed strip at the bottom of the
                            // top collar's back wall. The pad rests on
                            // it, so sliding the enclosure in cannot
                            // push the pad out the bottom. It sits
                            // flush with the cavity wall, so it never
                            // touches the enclosure.

// ---------------- Cradle collars ----------------
WALL         = 6;   // collar wall thickness -- deep enough to hold the
                     // M3 cap-head counterbore below (see
                     // JOINT_COUNTERBORE_DEPTH) with material behind it
RING_HEIGHT  = 14;  // cavity height of each collar, along the long (Z)
                     // axis. Both collars use the same value.
                     //
                     // Do not raise this much: the two M5 bolt heads
                     // have to stay reachable in the open span between
                     // the collars, and that span is what is left of
                     // the enclosure's length after both collars take
                     // their share. bolt_clearance below echoes how
                     // much room is left -- keep it positive.
RING_MARGIN_BOTTOM = 8; // gap from the cage's bottom to the cavity floor
FLOOR_THICK  = 3;   // solid floor under the bottom collar's cavity.
                     // Solid, not a perimeter lip: the floor foam pad
                     // needs backing across its whole area, or it
                     // dishes into the opening and the clamp goes soft.
DRAIN_DIA    = 5;   // drain holes through that floor -- the collar is
                     // closed all round now, so water needs a way out
ENTRY_CHAMFER = 2;  // lead-in flare at the top of each cavity, so the
                     // enclosure starts square instead of catching on
                     // an edge or peeling a back pad
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

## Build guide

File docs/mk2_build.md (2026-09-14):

# Mk2 build guide

Bench build of the Phase 2 logger on the 5 x 7 cm protoboard. See
[mk2.md](mk2.md) for the plan and the parts list. Phase 1 was skipped: all
the parts arrived together on 2026-09-12, so the ADXL375 goes straight onto
the XIAO.

Parts on hand: XIAO nRF52840 Sense Plus, ADXL375 breakout (Adafruit 5374),
microSD breakout+ (Adafruit 254), LiPo with JST, slide switch, tactile
button, 2.2k resistors, the existing HT16K33 bar display. Not bought: the
5 V boost and the BSS138 level shifter.

## Wiring

All logic is 3.3 V. Every module gets its power from the XIAO's 3V3 pin.

| XIAO pin | nRF52 port | Goes to |
|---|---|---|
| 3V3 | | ADXL375 VIN, microSD **3V** (not 5V, see below), display +, both pull-ups |
| GND | | ADXL375 GND, microSD GND, display - |
| D8 | P1.13 | SCK: ADXL375 SCL and microSD CLK |
| D10 | P1.15 | MOSI: ADXL375 SDA and microSD DI |
| D9 | P1.14 | MISO: ADXL375 SDO and microSD DO |
| D3 | P0.29 | ADXL375 CS |
| D2 | P0.28 | microSD CS |
| D0 | P0.02 | ADXL375 INT1 (data ready; wire it now, the logger uses it later) |
| D4 | P0.04 | SDA: display SDA, with 10k to 3V3 |
| D5 | P0.05 | SCL: display SCL, with 10k to 3V3 |
| D1 | P0.03 | Start button; other side to GND (`INPUT_PULLUP`, pressed = LOW) |
| BAT+ pad | | Slide switch, then LiPo red wire |
| BAT- pad | | LiPo black wire |

The BAT pads are on the underside of the XIAO, next to the USB-C connector.
They are pads, not pins, so the battery wires solder directly to them. Keep
those two leads short and strain-relieve them with a dab of hot glue.

Notes on the choices:

- **microSD power goes to its 3V pin, not its 5V pin.** The 5V pin feeds
  the breakout's regulator. With only 3.3 V in, the regulator sits at its
  dropout, and the card browns out during its own initialization, which is
  its highest-current moment. Symptoms: init errors 0x17 (card stuck in
  idle) or 0x12 (card lost right after reporting ready), while a meter
  still shows 3.3 V at idle. Feeding the 3V pin directly bypasses the
  regulator; Adafruit's forum confirms it as an input on 3.3 V systems.
  Leave the 5V pin empty and never put 5 V on that board.
- **One SPI bus, two devices.** The ADXL375 uses SPI mode 3 and the SD card
  uses mode 0. That is fine: each library sets the mode inside its own
  transaction. What matters is that each device releases MISO when its CS
  is high. The ADXL375 does. The microSD breakout+ has a level-shifter
  buffer on DO for this reason. The bring-up sketch tests it.
- **ADXL375 CS.** The breakout ties CS to 3.3 V through a resistor to
  default to I2C. Driving CS from D3 overrides that. Keep CS high when idle,
  which the sketch does.
- **Button.** `INPUT_PULLUP`, button to ground. No external resistor. This
  is the opposite polarity from the Mk1 wiring.
- **Switch in the battery line, on one leg only.** LiPo red to the
  switch's middle pin, switch's outer pin to the XIAO's BAT+ pad, LiPo
  black straight to BAT-. The switch never touches GND or the 3V3 rail:
  it is entirely on the raw battery net, which is why it belongs
  physically near the XIAO's BAT pads rather than wherever "a long edge"
  first suggested (see the layout diagram below). With the switch off and
  USB plugged in, the XIAO runs from USB but the cell does not charge.
  Turn the switch on to charge.
- **Charge current.** Default is 50 mA. The sketch drives P0.13 low for
  100 mA, which is 0.2 C for a 500 mAh cell. Do not use 100 mA with a cell
  under 200 mAh.
- **Display voltage.** The HT16K33 datasheet says 4.5 to 5.5 V. The
  backpack usually runs at 3.3 V, dimmer. Its input-high threshold is
  0.7 x VDD, so at 5 V it wants 3.5 V logic and the XIAO gives 3.3 V. Run
  it at 3.3 V for now and judge brightness outdoors. If it is too dim, buy
  the boost converter and the level shifter and run it at 5 V.

## Layout on the protoboard

Physical placement is up to you, but these matter:

1. **The ADXL375 is the reference part.** Solder it flat and square to the
   board edges. Write down which board edge each sensor axis points along,
   because the case design and the analysis both need it. The axis arrows
   are printed on the breakout.
2. **XIAO at one short edge**, USB-C facing out. It must be reachable for
   flashing and for USB readout once the case exists.
3. **microSD at the other short edge**, slot facing out, so a card can go
   in without lifting the board.
4. **Switch close to the XIAO's BAT pads,** since it's wired inline with
   the raw battery leads, not the rail. No button on this build.
5. **LiPo under the board**, held with a foam pad. Do not put it under
   the ADXL375.

Use male headers on every module, solder the headers into the protoboard,
and run the 28 AWG silicone wire on the underside. Solder each end of a
wire before cutting the next one, and check each net with the multimeter's
continuity beeper before applying power.

## Perfboard layout

A to-scale top and bottom view, drawn 2026-09-13:
https://claude.ai/code/artifact/c99e428d-f22b-4eea-8c8c-6359c3312635
It's what caught the switch placement above; use it to dry-fit before
soldering anything new, and correct it (or ask for a redraw) if the real
board disagrees.

## Bench log

**2026-09-12.** XIAO (a Sense Plus) soldered to the perfboard, nothing else
wired. Bring-up sketch flashed and reporting. Results with nothing wired:
ADXL375 fail, microSD fail, display no ACK, button released, battery about
3.7 V with no cell (the charger's open output). All as expected.

**The onboard IMU did not answer, now solved (2026-09-13).** Its internal
I2C bus (P0.07 SDA, P0.27 SCL) read low on both lines, on two different
Sense Plus boards, with the IMU supply pin P1.08 driven high. Seeed's
KiCad source for the Plus shows the IMU and its two 10k bus pull-ups all
fed from P1.08, exactly like the Sense. The cause: in the nRF52's standard
GPIO drive, P1.08 sags under the IMU's load and never reaches a high
level (it reads back low). In high-drive mode (`OUTPUT_H0H1`) it comes up,
and the bus follows within a millisecond. The plain Sense gets away with
standard drive; the Plus does not. Any code that powers this IMU on the
Plus must set the pin to high drive before the library's `begin()`. The
Seeed LSM6DS3 library does not, so it fails on the Plus as shipped. The
bring-up sketch does it. Gyro is back on the table.

**2026-09-12, later.** ADXL375 on female-female jumpers to the XIAO
headers. It answers: ID 0xE5, BW_RATE 0x0F (3200 Hz), DATA_FORMAT 0x0B,
POWER_CTL 0x08. Library path: 138 us per sample, about 6300 reads/s. Burst
path, 3000 samples at rest: mean vector 0.86 g (zero-g offset, per
datasheet), rms 0.16 to 0.19 g per axis (normal noise at 3200 Hz), 7 wild
samples including one all-zero triple. The wild samples are the jumpers,
not the sensor. Next: solder the seven wires, rerun, expect zero outliers.
The logger firmware must drop all-zero samples as a guard regardless.

**2026-09-12, ADXL375 soldered.** Seven wires on the underside. Report:
ID 0xE5, mean vector 0.67 g (x +0.60, y -0.02, z +0.29: zero-g offset,
needs a six-position trim later), rms 0.18 to 0.22 g per axis, minimum
0.10 g, maximum 1.83 g, no all-zero samples. The jumper glitches are gone.
Live resting peak through the library path is about 2.5 g: that is the
noise floor of 6300 raw samples a second at 3200 Hz bandwidth, and the
logger must not report raw single-sample peaks. Lower the bandwidth or
average a few samples, or both.

**2026-09-13, microSD.** Wired per the table, first with power on the
breakout's 5V pin: init failed every time (codes 0x17 and 0x12). Moved
power to the 3V pin: passes. Card 7580 MB FAT32. Write test, 200 x 512 B:
mean 1.8 ms, worst 38 ms. SPI bus sharing passes: the ADXL375 answers
after SD traffic. Onboard IMU passes on this board too with the
high-drive fix. Remaining: display, button, battery.

One trap for anyone probing the MISO line: the ADXL375 breakout has a
10k pull-down on SDO (it sets the I2C address). With nothing driving the
bus, MISO reads low against the MCU's pull-up. That is not a fault, and
it makes "DO stuck low" readings meaningless on this board.

**Logger buffer sizing.** A 38 ms SD stall at 1 kHz and 10 bytes per
sample is 380 bytes. A 4 KB ring buffer covers ten times that. RAM is not
a constraint; the nRF52840 has 256 KB.

**2026-09-13, display.** HT16K33 backpack on D4/D5 with one 10k pull-up
per line to 3V3, powered from 3V3, over the existing bar cable. Passes:
ACK at 0x70, shows 8888, then the live peak. Brightness outdoors not yet
judged; that decides the boost converter and level shifter. Note the
backpack's pins are labelled SDA and SCL, not D and C. Remaining: button,
switch and battery.

**2026-09-13, battery pads unreachable.** The XIAO's BAT pads are on its
underside and the module was already soldered to the perfboard. Fix: the
second XIAO gets its battery leads first, then replaces the first in place
(cut the header pins in the gap, pull the stubs one at a time, drop the
new module into the same holes). The order of work now puts the battery
leads before mounting.

**2026-09-13, display current corrupts the sensor.** With the display
connected and blank: ADXL375 scatter 0.17 g per axis, zero glitches. With
8888 lit: 0.69 g and 341 glitches in 3000, some all-zero samples on the
slower library path. Brightness setting does not help (the backpack dims
by pulse width, so the pulse amplitude is unchanged). A 100 nF at the
sensor's pins removes the all-zero samples only. Cause: the backpack's
multiplexed LED current pulses sag the XIAO's 3.3 V regulator and lift the
shared ground. Fix, ordered: Adafruit MiniBoost 5 V (4654) to run the
display from the battery, Adafruit BSS138 level shifter (757) for the two
I2C lines at 5 V, and 100 µF electrolytics at the backpack and the boost
input. Until then the display is usable for bring-up only, and any sensor
measurement must be taken with the display blank.

Also noted: the ADXL375 is powered through its 3Vo pin, not VIN, which
bypasses the breakout's regulator. It works and stays that way.

## Order of work

Do the steps in this order. Run the bring-up sketch after each step and
read the report. Each subsystem reports on its own, so a half-wired board
gives a half-passing report, which is what you want.

1. **Solder the battery leads to the XIAO's BAT pads FIRST.** The pads
   are on the module's underside. Once the module is on the perfboard they
   cannot be reached. This was learned the hard way on 2026-09-13 and cost
   a module swap. Route the two leads off the USB end.
2. **Solder the headers.** ADXL375, microSD breakout, XIAO. Tin the iron,
   flux the pads, one pin at a time. Check for bridges with the beeper.
3. **Flash the bring-up sketch with nothing wired.** Confirm the toolchain
   and the USB serial link. Expect every test to fail except the onboard
   IMU, the button, and the battery.
4. **Wire power and the ADXL375.** 3V3, GND, SCK, MOSI, MISO, CS, INT1.
   Expect `PASS ADXL375` with ID 0xE5 and about 1.0 g at rest.
5. **Wire the microSD.** Add CLK, DI, DO, CS, and power to its 3V pin.
   Put a formatted FAT32 card in. Expect `PASS microSD`, `PASS microSD write`, and
   `PASS SPI bus sharing`. Note the worst-case write time; it sets the
   logger's buffer size.
6. **Wire the display.** SDA to D4, SCL to D5, + and -, and one 10k
   pull-up from each data line to 3V3. Expect 8888 on the display.
7. **Wire the button.** Expect the live line to flip to PRESSED.
8. **Solder the switch and the battery.** Expect a battery reading between
   3.0 and 4.2 V. Unplug USB and confirm the board runs on the cell.
9. **Measure everything with calipers** and update the footprint table in
   [mk2.md](mk2.md). This unblocks the case design.

## Logger firmware

`Shredometer_Mk2/Shredometer_Mk2.ino` is the real logger, distinct from
the bring-up sketch. Differences from bring-up, and why:

- **ADXL375 FIFO, not single-sample reads.** The chip has a 32-entry FIFO
  in stream mode. The loop drains it as often as it can rather than
  reading one sample at a time, so a slow pass through `loop()` (an SD
  write, say) does not lose samples as long as it is under the FIFO's
  time cushion. At 1600 Hz that cushion is 20 ms; the bring-up write test
  measured a worst case of 38 ms, so overruns are expected under load and
  are counted, not hidden. `BW_RATE` defaults to 1600 Hz rather than
  3200 Hz: half the bandwidth for about 1.4x lower noise, still comfortably
  above anything a bike hit produces, and double the FIFO's time cushion.
- **Binary log, not CSV.** 8 bytes a record instead of about 65 bytes a
  CSV row, so the card and the bus carry far more samples for the same
  I/O cost. `scripts/mk2_to_csv.py` converts a log to the CSV
  `analyze_log.py` already reads, so the existing reports run unchanged.
- **No display, no button.** The first ride does not need either; the
  power switch is the start button. A sector's first record is always a
  time and sequence marker, so gaps and clock drift show up in the file
  itself even with nothing to read it live.
- **Onboard IMU included by default,** with the Sense Plus high-drive fix
  from the bench log baked in, and the "never touch a bus that reads low"
  guard from bring-up.
- **Serial commands are optional, for the bench only:** `i` info, `s`
  stop, `r` start a new file, `d` dump the closed file's raw bytes. None
  of this is needed for a ride; power on to power off is the whole flow.
- **LED as a status light** (the same three pins the mbed core drives
  during `initVariant()`): blue while starting up, off and logging (green
  blinks every 500 ms) once both the ADXL375 and the SD card are up, solid
  red if either is missing so a dead sensor doesn't ride silently.

Not yet run end to end on real hardware: the bring-up sketch proved every
subsystem individually, but the logger's FIFO-draining loop and its file
lifecycle (`preAllocate`, `truncate`, the header sector) have only been
tested against a synthetic binary file, not the perfboard.

To try it: `scripts/flash_xiao.sh Shredometer_Mk2`, let it run a minute
with an SD card in, then `s` to stop and `d` to dump, or pull the card and
run `python3 scripts/mk2_to_csv.py path/to/MK2_000.BIN`. Compare the
reported sample rate and overrun count against the FIFO cushion above.

## Toolchain

Installed on 2026-09-12:

```
arduino-cli config add board_manager.additional_urls https://files.seeedstudio.com/arduino/package_seeeduino_boards_index.json
arduino-cli core update-index
arduino-cli core install Seeeduino:nrf52
arduino-cli lib install "Adafruit ADXL375"
python3 -m venv ~/.local/share/adafruit-nrfutil-venv
~/.local/share/adafruit-nrfutil-venv/bin/pip install adafruit-nrfutil
ln -s ~/.local/share/adafruit-nrfutil-venv/bin/adafruit-nrfutil ~/.local/bin/
```

Use the `Seeeduino:nrf52` core, not the mbed one. It is the Adafruit-derived
core with TinyUSB, which is what USB mass-storage readout will need later.
The core needs `adafruit-nrfutil` on the PATH to build and upload. There is
no pipx on this machine, hence the venv.

Two library traps, both hit on 2026-09-12:

- **Do not install the SdFat library.** The core bundles SdFat 2.2.1, and
  the current library-manager release (2.3.0) fails to compile against this
  core's Print class. If `arduino-cli lib list` shows SdFat, uninstall it.
- **The Seeed LSM6DS3 library needs two things on the Sense Plus.** The
  right board target, so it picks the internal bus (Wire1): this core
  defines `TARGET_SEEED_XIAO_NRF52840_SENSE_PLUS`, so that part is fine.
  And the IMU power pin in high-drive mode, which the library does not do.
  Call `pinMode(PIN_LSM6DS3TR_C_POWER, OUTPUT_H0H1)` and drive it high
  before `begin()`. See the bench log. Also note `Adafruit_TinyUSB.h` must
  be included in any sketch that uses `Serial` but no other core library;
  `Wire.h` or `SPI.h` pull it in, a bare sketch does not link.
- **Never do an address-only I2C probe on this core.** The nRF52 Wire
  driver has no timeouts, and `endTransmission()` with zero data bytes
  waits forever for a start event that never comes. Always write at least
  one byte before `endTransmission()`. An I2C scanner sketch written for
  AVR hangs here for this reason.

**Which board.** The unit on the bench identifies its bootloader over USB
as "XIAO nRF52840 Sense Plus" (vendor 2886, product 0065). The plain Sense
bootloader is product 0045. Check with `lsusb -d 2886:` while the board is
in the bootloader. Build for the board you have. D0 to D10 are the same on
both, but the battery, charger, and IMU pin macros differ.

```
scripts/flash_xiao.sh Shredometer_Mk2_Bringup
```

The script compiles, then flashes the right way for the board's state. If
the board is running an app, it uses `arduino-cli upload`. If the board is
already in its bootloader, it calls `adafruit-nrfutil` directly, because
arduino-cli's 1200-baud port touch breaks a bootloader that is already
waiting and the upload fails with "No data received on serial port".
Set `FQBN=Seeeduino:nrf52:xiaonRF52840Sense` in the environment for a
plain Sense.

The bring-up sketch runs its tests when a host opens the port, not at
boot, so the report is never missed. Send `r` in the monitor to run the
tests again after wiring the next subsystem. No reflash needed.

**Serial monitor.** The XIAO is USB CDC, so any terminal works, unlike the
Nano Every. Start the monitor only after the upload has finished and the
board has come back.

```
arduino-cli board list
arduino-cli monitor -p /dev/ttyACM0 -c baudrate=115200
```

The board disconnects and re-enumerates on every upload and every reset.
A monitor that was open across that event keeps a dead handle and shows
nothing forever, and the board can come back as `/dev/ttyACM1` while the
dead handle holds `/dev/ttyACM0`. If the monitor sits at "Connecting",
press Ctrl-C, run `arduino-cli board list` to find the current port, and
start the monitor again. Never leave a monitor open during an upload: it
can also wedge the bootloader's DFU session, which then needs a USB
unplug and replug to recover.

If the upload cannot find the board, double-tap the reset button on the
XIAO. The board enters its bootloader and shows up as a USB drive. Upload
again.

## What the bring-up report should look like

```
Shredometer Mk2 bring-up
------------------------
PASS  ADXL375: ID 0xE5, 30 us per sample, at rest |a| = 1.02 g (expect ~1.0)
PASS  microSD: card 7580 MB, FAT32
PASS  microSD write: 200 x 512 B: mean 900 us, worst 45000 us
PASS  SPI bus sharing: ADXL375 still answers after SD use
PASS  LSM6DS3 (onboard): WHO_AM_I 0x6A (expect 0x6A or 0x69)
PASS  HT16K33 display: ACK at 0x70, showing 8888. Judge brightness at 3.3 V by eye.
PASS  Button: reads released
PASS  Battery: 3.87 V (3.0 empty, 4.2 full; ~0 V means no cell on BAT pads)
```

The timing numbers above are placeholders. Record the real ones here.

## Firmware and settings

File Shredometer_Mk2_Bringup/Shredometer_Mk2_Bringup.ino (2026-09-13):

// Shredometer Mk2 bring-up
// ------------------------
// Tests each subsystem on the XIAO nRF52840 Sense, one at a time, and
// reports PASS or FAIL for each over USB serial. Wire one subsystem,
// flash this, read the report, wire the next. Nothing here logs a
// ride; that is Shredometer_Mk2 (to come).
//
// Board:  Seeed XIAO nRF52840 Sense Plus (bootloader reports USB PID 0x0065)
// FQBN:   Seeeduino:nrf52:xiaonRF52840SensePlus
//         (plain Sense: Seeeduino:nrf52:xiaonRF52840Sense, bootloader PID 0x0045)
// Build:  arduino-cli compile --fqbn Seeeduino:nrf52:xiaonRF52840SensePlus Shredometer_Mk2_Bringup
// Upload: arduino-cli upload -p /dev/ttyACM0 --fqbn Seeeduino:nrf52:xiaonRF52840SensePlus Shredometer_Mk2_Bringup
// D0 to D10 are the same on both boards. The battery, charger, and IMU
// pins come from the variant's macros, so the FQBN must match the board.
//
// See docs/mk2_build.md for the wiring table these pins come from.

#include <SPI.h>
#include <Wire.h>
#include <Adafruit_ADXL375.h>
#include <SdFat.h>
#include <Adafruit_LEDBackpack.h>

// ---------------- Pins (XIAO D numbers) ----------------
// Hardware SPI is fixed: D8 SCK, D9 MISO, D10 MOSI.
// Hardware I2C is fixed: D4 SDA, D5 SCL.
const uint8_t PIN_ADXL_CS   = 3;   // ADXL375 chip select
const uint8_t PIN_ADXL_INT1 = 0;   // ADXL375 INT1 (data ready), optional for bring-up
const uint8_t PIN_SD_CS     = 2;   // microSD chip select
const uint8_t PIN_BUTTON    = 1;   // start button, to GND, INPUT_PULLUP
const uint8_t PIN_HICHG     = PIN_CHARGING_CURRENT;  // P0.13: LOW = 100 mA charge, input = 50 mA

const uint8_t DISPLAY_ADDR  = 0x70;
// 0 to 15. Full brightness with all segments lit pulls well over 100 mA
// in pulses off the shared 3.3 V rail, and the ADXL375 reads that as
// noise on every axis (measured 2026-09-13: 0.5 g rms and bit errors on
// the SPI bus at 15; 0.2 g rms and none with the display unpowered).
const uint8_t DISPLAY_BRIGHTNESS = 4;

// ---------------- Devices ----------------
Adafruit_ADXL375 adxl(PIN_ADXL_CS, &SPI, 12345);
SdFs sd;
Adafruit_7segment display;

bool okAdxl = false, okSd = false, okImu = false, okDisplay = false;
bool displayUp = false;   // display.begin() has run; survives reruns

static void report(const char *name, bool ok, const char *detail = "") {
  Serial.print(ok ? "PASS  " : "FAIL  ");
  Serial.print(name);
  if (detail[0]) { Serial.print(": "); Serial.print(detail); }
  Serial.println();
}

// ---------------- ADXL375 over SPI ----------------
static void testAdxl() {
  char buf[96];
  if (!adxl.begin()) {
    // Say what came back, so a wiring fault can be located.
    //   0x00 every time: MISO stuck low, or the sensor never selected (CS, or no power).
    //   0xFF every time: MISO floating or open (SDO wire), or no power to the sensor.
    //   other, varying:  clock or data wire swapped or open.
    uint8_t ids[4];
    for (int i = 0; i < 4; i++) ids[i] = adxl.getDeviceID();
    pinMode(PIN_SPI_MISO, INPUT_PULLDOWN); delayMicroseconds(200); bool misoDown = digitalRead(PIN_SPI_MISO);
    pinMode(PIN_SPI_MISO, INPUT_PULLUP);   delayMicroseconds(200); bool misoUp   = digitalRead(PIN_SPI_MISO);
    SPI.begin();  // give the pin back to SPI
    snprintf(buf, sizeof buf, "no ID 0xE5. Read %02X %02X %02X %02X. MISO idle: %s",
             ids[0], ids[1], ids[2], ids[3],
             (misoDown != misoUp) ? "floating (SDO wire open, or sensor unpowered)"
                                  : (misoUp ? "driven high" : "driven low"));
    report("ADXL375", false, buf);
    return;
  }
  uint8_t id = adxl.getDeviceID();
  if (id != 0xE5) {
    snprintf(buf, sizeof buf, "device ID 0x%02X, expected 0xE5", id);
    report("ADXL375", false, buf);
    return;
  }
  adxl.setDataRate(ADXL3XX_DATARATE_3200_HZ);

  // Time 1000 raw reads. Each is three 2-byte register reads through
  // the library; the real firmware will do one 6-byte burst instead.
  int16_t x = 0, y = 0, z = 0;
  uint32_t t0 = micros();
  for (int i = 0; i < 1000; i++) { x = adxl.getX(); y = adxl.getY(); z = adxl.getZ(); }
  uint32_t us = (micros() - t0) / 1000;

  float gx = x * 0.049f, gy = y * 0.049f, gz = z * 0.049f;
  float mag = sqrtf(gx * gx + gy * gy + gz * gz);
  snprintf(buf, sizeof buf, "ID 0xE5, %lu us per sample, at rest |a| = %.2f g (expect ~1.0)",
           (unsigned long)us, mag);
  okAdxl = true;
  report("ADXL375", true, buf);
  if (mag < 0.7f || mag > 1.3f) {
    Serial.println("      WARN: |a| at rest is not near 1 g. Hold the board still and rerun.");
  }
  if (displayUp) {
    // On a rerun the display is up: measure with it blanked (no LED
    // current, connection intact) and with every segment lit.
    display.clear(); display.writeDisplay(); delay(50);
    Serial.println("      display BLANK:");  adxlStats();
    display.print(8888); display.writeDisplay(); delay(50);
    Serial.println("      display 8888:");   adxlStats();
  } else {
    adxlStats();
  }
}

// Read a register directly, outside the library.
static uint8_t adxlReg(uint8_t reg) {
  SPI.beginTransaction(SPISettings(1000000, MSBFIRST, SPI_MODE3));
  digitalWrite(PIN_ADXL_CS, LOW);
  SPI.transfer(reg | 0x80);
  uint8_t v = SPI.transfer(0);
  digitalWrite(PIN_ADXL_CS, HIGH);
  SPI.endTransaction();
  return v;
}

// One 6-byte burst read of X, Y, Z. This is how the logger will read.
static void adxlBurst(int16_t *x, int16_t *y, int16_t *z) {
  uint8_t b[6];
  SPI.beginTransaction(SPISettings(1000000, MSBFIRST, SPI_MODE3));
  digitalWrite(PIN_ADXL_CS, LOW);
  SPI.transfer(0x32 | 0x80 | 0x40);   // DATAX0, read, multi-byte
  for (int i = 0; i < 6; i++) b[i] = SPI.transfer(0);
  digitalWrite(PIN_ADXL_CS, HIGH);
  SPI.endTransaction();
  *x = (int16_t)(b[0] | (b[1] << 8));
  *y = (int16_t)(b[2] | (b[3] << 8));
  *z = (int16_t)(b[4] | (b[5] << 8));
}

// 3000 burst samples at rest: mean vector, scatter per axis, outliers.
// Clean data is a mean magnitude near 1 g, rms of a few counts (0.1 to
// 0.3 g), and zero outliers. Outliers with an otherwise clean mean point
// at the wiring, not the sensor.
static void adxlStats() {
  char buf[120];
  snprintf(buf, sizeof buf, "      regs: BW_RATE 0x%02X (0x0F = 3200 Hz), DATA_FORMAT 0x%02X, POWER_CTL 0x%02X",
           adxlReg(0x2C), adxlReg(0x31), adxlReg(0x2D));
  Serial.println(buf);
  const int N = 3000;
  static int16_t xs[N], ys[N], zs[N];
  double sx = 0, sy = 0, sz = 0;
  int zeros = 0;
  for (int i = 0; i < N; i++) {
    adxlBurst(&xs[i], &ys[i], &zs[i]);
    sx += xs[i]; sy += ys[i]; sz += zs[i];
    if (xs[i] == 0 && ys[i] == 0 && zs[i] == 0) zeros++;
    delayMicroseconds(320);   // about one 3200 Hz sample period
  }
  float mx = sx / N, my = sy / N, mz = sz / N;
  // Scatter about the mean, and glitches: samples further than 1.5 g
  // from the mean vector. Noise at 0.2 g rms per axis essentially never
  // gets there, so any count here is the wiring.
  double sxx = 0, syy = 0, szz = 0; int far = 0; float devMax = 0;
  for (int i = 0; i < N; i++) {
    float dx = xs[i] - mx, dy = ys[i] - my, dz = zs[i] - mz;
    sxx += dx * dx; syy += dy * dy; szz += dz * dz;
    float d = sqrtf(dx * dx + dy * dy + dz * dz) * 0.049f;
    if (d > devMax) devMax = d;
    if (d > 1.5f) far++;
  }
  snprintf(buf, sizeof buf, "      mean  x %+.2f  y %+.2f  z %+.2f g   |mean| %.2f g (offsets make this differ from 1.0)",
           mx * 0.049f, my * 0.049f, mz * 0.049f, sqrtf(mx * mx + my * my + mz * mz) * 0.049f);
  Serial.println(buf);
  snprintf(buf, sizeof buf, "      rms   x %.2f  y %.2f  z %.2f g   worst deviation %.2f g   glitches %d, all-zero %d, of %d",
           sqrtf(sxx / N) * 0.049f, sqrtf(syy / N) * 0.049f, sqrtf(szz / N) * 0.049f, devMax, far, zeros, N);
  Serial.println(buf);
}

// ---------------- microSD over shared SPI ----------------
static void testSd() {
  char buf[160];
  bool ok = sd.begin(SdSpiConfig(PIN_SD_CS, SHARED_SPI, SD_SCK_MHZ(8)));
  if (!ok) {
    snprintf(buf, sizeof buf, "begin() at 8 MHz failed: code 0x%02X data 0x%02X. Retrying at 1 MHz...",
             sd.sdErrorCode(), sd.sdErrorData());
    Serial.print("      "); Serial.println(buf);
    delay(200);
    ok = sd.begin(SdSpiConfig(PIN_SD_CS, SHARED_SPI, SD_SCK_MHZ(1)));
  }
  if (!ok) {
    snprintf(buf, sizeof buf, "code 0x%02X data 0x%02X (0x01 CMD0: no reply; 0x12 CMD58 with data 0: DO stuck low)",
             sd.sdErrorCode(), sd.sdErrorData());
    report("microSD", false, buf);
    // DO idle level, seen straight from the pin. With the card selected and
    // no clock, a ready card drives DO high. Deselected, the breakout's
    // buffer should release DO and the line floats.
    SPI.end();
    pinMode(PIN_SPI_MISO, INPUT);
    digitalWrite(PIN_SD_CS, LOW);  delay(2); bool selLow = digitalRead(PIN_SPI_MISO);
    pinMode(PIN_SPI_MISO, INPUT_PULLUP); delay(1); bool selUp = digitalRead(PIN_SPI_MISO);
    digitalWrite(PIN_SD_CS, HIGH); delay(2);
    pinMode(PIN_SPI_MISO, INPUT_PULLDOWN); delay(1); bool deselDown = digitalRead(PIN_SPI_MISO);
    pinMode(PIN_SPI_MISO, INPUT_PULLUP);   delay(1); bool deselUp = digitalRead(PIN_SPI_MISO);
    SPI.begin();
    snprintf(buf, sizeof buf, "DO with card selected: %s (ready card = high). Deselected: %s",
             selUp ? (selLow ? "high" : "floating") : "driven LOW (busy, browned out, or DO shorted)",
             (deselDown != deselUp) ? "floating (buffer released, good)" : (deselUp ? "driven high" : "driven LOW"));
    Serial.print("      "); Serial.println(buf);
    // Each SD wire as a plain input: does anything else drive it?
    // A wire that only goes to the SD board's input should float.
    // The ADXL375's CS stays high so it is out of the picture.
    SPI.end();
    struct { const char *name; uint8_t pin; } w[] = {
      {"CS D2", PIN_SD_CS}, {"CLK D8", PIN_SPI_SCK}, {"DI D10", PIN_SPI_MOSI}, {"DO D9", PIN_SPI_MISO}};
    Serial.print("      wires as inputs:");
    for (auto &x : w) {
      pinMode(x.pin, INPUT_PULLDOWN); delay(1); bool d = digitalRead(x.pin);
      pinMode(x.pin, INPUT_PULLUP);   delay(1); bool u = digitalRead(x.pin);
      Serial.print("  "); Serial.print(x.name); Serial.print("=");
      Serial.print(d != u ? "floating" : (u ? "HIGH" : "LOW"));
    }
    Serial.println();
    pinMode(PIN_SD_CS, OUTPUT); digitalWrite(PIN_SD_CS, HIGH);
    SPI.begin();
    return;
  }
  uint32_t mb = (uint32_t)(sd.card()->sectorCount() / 2048);
  snprintf(buf, sizeof buf, "card %lu MB, FAT%d", (unsigned long)mb, sd.fatType());
  report("microSD", true, buf);

  // Write 200 x 512 bytes and record the slowest write. This is the
  // number that decides how much RAM buffering the logger needs.
  FsFile f = sd.open("BRINGUP.BIN", O_WRONLY | O_CREAT | O_TRUNC);
  if (!f) { report("microSD write", false, "could not open BRINGUP.BIN"); return; }
  static uint8_t block[512];
  for (int i = 0; i < 512; i++) block[i] = i;
  uint32_t worst = 0, total = 0;
  for (int i = 0; i < 200; i++) {
    uint32_t t0 = micros();
    f.write(block, sizeof block);
    uint32_t dt = micros() - t0;
    total += dt;
    if (dt > worst) worst = dt;
  }
  f.close();
  snprintf(buf, sizeof buf, "200 x 512 B: mean %lu us, worst %lu us",
           (unsigned long)(total / 200), (unsigned long)worst);
  okSd = true;
  report("microSD write", true, buf);
}

// After the SD card has been used, the ADXL375 must still answer. If
// this fails, the SD board is holding MISO when it is not selected.
static void testBusSharing() {
  if (!okAdxl || !okSd) { report("SPI bus sharing", false, "skipped, needs both SPI devices"); return; }
  uint8_t id = adxl.getDeviceID();
  report("SPI bus sharing", id == 0xE5,
         id == 0xE5 ? "ADXL375 still answers after SD use"
                    : "ADXL375 ID wrong after SD use: SD board is not releasing MISO");
}

// The nRF52 Wire driver has no timeouts: a bus held low hangs it forever.
// Check both lines idle high (with the internal pull-up) before using it.
// Returns 0 if OK, else a bitmask: 1 = SDA low, 2 = SCL low.
static uint8_t i2cBusHeldLow(uint8_t sda, uint8_t scl) {
  pinMode(sda, INPUT_PULLUP); pinMode(scl, INPUT_PULLUP);
  delayMicroseconds(200);
  uint8_t bad = 0;
  if (digitalRead(sda) == LOW) bad |= 1;
  if (digitalRead(scl) == LOW) bad |= 2;
  return bad;
}

// ---------------- Onboard LSM6DS3 IMU ----------------
// The Sense's IMU hangs off a second, internal I2C bus (Wire1, P0.07 and
// P0.27) and is powered from a GPIO, P1.08, which also feeds the bus
// pull-ups. On the Sense Plus that pin MUST be in high-drive mode: in
// standard drive it sags under the IMU's load, the supply never comes
// up, and the bus reads low (measured 2026-09-13 on two boards). The
// Seeed LSM6DS3 library uses plain OUTPUT, so it fails on the Plus
// unless the pin is set up like this before its begin().
// Bring-up reads WHO_AM_I directly, with no library.
static void testImu() {
  char buf[96];
  pinMode(PIN_LSM6DS3TR_C_POWER, OUTPUT_H0H1);
  digitalWrite(PIN_LSM6DS3TR_C_POWER, HIGH);
  delay(50);
  uint8_t bad = i2cBusHeldLow(PIN_WIRE1_SDA, PIN_WIRE1_SCL);
  if (bad) {
    snprintf(buf, sizeof buf, "internal bus held low (SDA %s, SCL %s): IMU unpowered or on other pins",
             (bad & 1) ? "LOW" : "ok", (bad & 2) ? "LOW" : "ok");
    report("LSM6DS3 (onboard)", false, buf);
    return;
  }
  Wire1.begin();
  Wire1.beginTransmission(0x6A);
  Wire1.write(0x0F);                       // WHO_AM_I
  if (Wire1.endTransmission(false) != 0 || Wire1.requestFrom(0x6A, 1) != 1) {
    report("LSM6DS3 (onboard)", false, "no answer on Wire1 at 0x6A. This is on the XIAO itself.");
    return;
  }
  uint8_t who = Wire1.read();
  snprintf(buf, sizeof buf, "WHO_AM_I 0x%02X (expect 0x6A or 0x69)", who);
  okImu = (who == 0x6A || who == 0x69);
  report("LSM6DS3 (onboard)", okImu, buf);
}

// ---------------- HT16K33 display over I2C ----------------
static void testDisplay() {
  uint8_t bad = i2cBusHeldLow(PIN_WIRE_SDA, PIN_WIRE_SCL);
  if (bad) {
    report("HT16K33 display", false, (bad & 1) ? "SDA (D4) held low" : "SCL (D5) held low");
    return;
  }
  Wire.begin();
  Wire.setClock(100000);   // long cable to the bars: keep it slow
  // Probe with one data byte. The nRF52 Wire driver has no timeouts,
  // and a zero-length write never raises TXSTARTED, so an address-only
  // probe hangs forever. 0x21 is the HT16K33 "oscillator on" command,
  // which begin() sends anyway.
  Wire.beginTransmission(DISPLAY_ADDR);
  Wire.write(0x21);
  if (Wire.endTransmission() != 0) {
    report("HT16K33 display", false, "no ACK at 0x70. Check D (SDA=D4), C (SCL=D5), +, -, pull-ups.");
    return;
  }
  display.begin(DISPLAY_ADDR);
  display.setBrightness(DISPLAY_BRIGHTNESS);
  display.print(8888);
  display.writeDisplay();
  okDisplay = true; displayUp = true;
  report("HT16K33 display", true, "ACK at 0x70, showing 8888. Judge brightness at 3.3 V by eye.");
}

// ---------------- Button ----------------
static void testButton() {
  bool pressed = digitalRead(PIN_BUTTON) == LOW;
  report("Button", true, pressed ? "reads PRESSED now (should be released)" : "reads released");
}

// ---------------- Battery ----------------
static float readBattery() {
  // Divider on the XIAO is 1 M / 510 k, so Vbat = Vpin * 1510 / 510.
  // Reference 2.4 V internal, 12-bit.
  digitalWrite(VBAT_ENABLE, LOW);
  analogReference(AR_INTERNAL_2_4);
  analogReadResolution(12);
  uint32_t raw = 0;
  for (int i = 0; i < 8; i++) raw += analogRead(PIN_VBAT);
  raw /= 8;
  return raw * (2.4f / 4096.0f) * (1510.0f / 510.0f);
}

static void testBattery() {
  char buf[96];
  pinMode(VBAT_ENABLE, OUTPUT);
  pinMode(PIN_HICHG, OUTPUT);
  digitalWrite(PIN_HICHG, LOW);   // 100 mA charge; fine for a 500 mAh cell
  float v = readBattery();
  snprintf(buf, sizeof buf, "%.2f V (3.0 empty, 4.2 full; ~0 V means no cell on BAT pads)", v);
  report("Battery", true, buf);
}

void setup() {
  Serial.begin(115200);
  pinMode(PIN_ADXL_CS, OUTPUT); digitalWrite(PIN_ADXL_CS, HIGH);
  pinMode(PIN_SD_CS, OUTPUT);   digitalWrite(PIN_SD_CS, HIGH);
  pinMode(PIN_ADXL_INT1, INPUT);
  pinMode(PIN_BUTTON, INPUT_PULLUP);
  SPI.begin();
}

// The tests run once a host opens the port, not at boot, so the report
// is never missed. Send 'r' over serial to run them again after wiring
// the next subsystem; no reflash needed.
static void runTests() {
  okAdxl = okSd = okImu = okDisplay = false;   // a rerun starts from nothing
  Serial.println();
  Serial.println("Shredometer Mk2 bring-up");
  Serial.println("------------------------");
  // One line before each test, so a hang shows which test it is in.
  Serial.println("-- ADXL375");         testAdxl();
  Serial.println("-- microSD");         testSd();
  Serial.println("-- SPI bus sharing"); testBusSharing();
  Serial.println("-- LSM6DS3");         testImu();
  Serial.println("-- display");         testDisplay();
  Serial.println("-- button");          testButton();
  Serial.println("-- battery");         testBattery();
  Serial.println("------------------------");
  Serial.println("Live: peak |a| over each second, button, battery. Send 'r' to rerun the tests.");
}

void loop() {
  static bool ran = false;
  static uint32_t lastPrint = 0;
  static float peak = 0;
  static uint32_t samples = 0;

  if (!Serial) { ran = false; return; }   // wait for a host; rerun on reconnect
  if (!ran) { delay(300); runTests(); ran = true; }
  if (Serial.available() && Serial.read() == 'r') { ran = false; return; }

  if (okAdxl) {
    int16_t x = adxl.getX(), y = adxl.getY(), z = adxl.getZ();
    float gx = x * 0.049f, gy = y * 0.049f, gz = z * 0.049f;
    float mag = sqrtf(gx * gx + gy * gy + gz * gz);
    if (mag > peak) peak = mag;
    samples++;
  }

  if (millis() - lastPrint >= 1000) {
    lastPrint = millis();
    Serial.print("peak |a| ");
    Serial.print(peak, 1);
    Serial.print(" g over ");
    Serial.print(samples);
    Serial.print(" reads   button ");
    Serial.print(digitalRead(PIN_BUTTON) == LOW ? "PRESSED " : "released");
    Serial.print("   bat ");
    Serial.print(readBattery(), 2);
    Serial.println(" V");
    if (okDisplay) {
      display.print(peak, 1);
      display.writeDisplay();
    }
    peak = 0;
    samples = 0;
  }
}

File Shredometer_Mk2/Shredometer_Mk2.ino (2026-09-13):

// Shredometer Mk2 logger
// ----------------------
// XIAO nRF52840 Sense Plus + ADXL375 (SPI) + microSD (SPI) + onboard
// LSM6DS3 (internal I2C). Logs from power-on until power-off. No display,
// no button: the power switch is the start button.
//
// Data path
//   ADXL375 runs at ADXL_ODR_HZ with its 32-entry FIFO in stream mode.
//   The main loop drains the FIFO as often as it can, packs samples into
//   512-byte sectors, and writes each full sector to a pre-allocated file.
//   The FIFO is the cushion against SD write stalls: at 1600 Hz it holds
//   20 ms. A stall longer than that loses samples, and the sensor reports
//   it through its overrun bit, which is counted and logged, so a gap is
//   always visible in the data rather than silently absent.
//   The LSM6DS3 gyro and accelerometer are read at about 104 Hz on the
//   internal bus and logged alongside.
//
// Log format (MK2_NNN.BIN)
//   Sector 0: Header (below), rest zero.
//   Every later sector: 64 records of 8 bytes. The first record in each
//   sector is a REC_TIME marker: millis() when the sector was started, a
//   sector sequence number, and the overrun count during the previous
//   sector. The other 63 are samples in the order they were taken.
//   scripts/mk2_to_csv.py turns this into the CSV the analysis reads.
//
// Serial (USB) is optional. Commands when connected:
//   i  print counters      s  stop and close the current file
//   r  start a new file    d  dump the last closed file (raw bytes)
//
// Build: scripts/flash_xiao.sh Shredometer_Mk2

#include <Adafruit_TinyUSB.h>
#include <SPI.h>
#include <Wire.h>
#include <SdFat.h>

// ---------------- Pins ----------------
const uint8_t PIN_ADXL_CS   = 3;
const uint8_t PIN_ADXL_INT1 = 0;   // wired, unused: the FIFO is polled
const uint8_t PIN_SD_CS     = 2;

// ---------------- Rates ----------------
// ADXL375 BW_RATE codes: 0x0F 3200 Hz, 0x0E 1600 Hz, 0x0D 800 Hz.
// Lower halves the FIFO's time cushion per step up, and cuts noise by
// about 1.4 per step down. 1600 gives 800 Hz bandwidth and 20 ms of FIFO.
const uint8_t  ADXL_BW_RATE_REG = 0x0E;
const float    ADXL_ODR_HZ      = 1600.0f;
const float    ADXL_G_PER_LSB   = 0.049f;
const uint32_t IMU_PERIOD_US    = 9615;    // 104 Hz, the LSM6DS3's own rate
const float    GYRO_DPS_PER_LSB = 0.070f;  // 2000 dps full scale
const float    IMUACC_G_PER_LSB = 0.000488f; // 16 g full scale
const uint32_t SYNC_PERIOD_MS   = 5000;    // directory entry update
const uint32_t PREALLOC_BYTES   = 256UL * 1024 * 1024;

// ---------------- Log format ----------------
struct __attribute__((packed)) Rec { uint8_t type; uint8_t flags; int16_t a, b, c; };
enum : uint8_t { REC_ADXL = 0, REC_GYRO = 1, REC_IMUACC = 2, REC_TIME = 3 };
struct __attribute__((packed)) Header {
  char     magic[8];        // "SHRDMK2"
  uint16_t version;         // 1
  uint16_t rec_size;        // 8
  uint16_t sector_size;     // 512
  uint16_t reserved;
  float    adxl_odr_hz;
  float    adxl_g_per_lsb;
  float    gyro_dps_per_lsb;
  float    imuacc_g_per_lsb;
  float    imu_hz;
  uint32_t start_millis;
};
static_assert(sizeof(Rec) == 8, "record size");
const int SECTOR = 512;
const int RECS_PER_SECTOR = SECTOR / sizeof(Rec);

// ---------------- State ----------------
SdFs sd;
FsFile file;
char lastName[16] = "";
bool logging = false, adxlOk = false, imuOk = false, sdOk = false;

uint8_t  sector[SECTOR];
int      fill = 0;
uint16_t seq = 0;
uint32_t overrunsTotal = 0, overrunsSinceMarker = 0, zerosTotal = 0;
uint32_t sectorsWritten = 0, worstWriteUs = 0, adxlSamples = 0, imuSamples = 0;
uint32_t lastSync = 0, lastImuUs = 0, lastBlink = 0;

// ---------------- LEDs (active low) ----------------
static void led(uint8_t pin, bool on) { digitalWrite(pin, on ? LOW : HIGH); }
static void ledsOff() { led(LED_RED, false); led(LED_GREEN, false); led(LED_BLUE, false); }

// ---------------- ADXL375, direct SPI ----------------
static const SPISettings ADXL_SPI(4000000, MSBFIRST, SPI_MODE3);
static uint8_t adxlRead(uint8_t reg) {
  SPI.beginTransaction(ADXL_SPI); digitalWrite(PIN_ADXL_CS, LOW);
  SPI.transfer(reg | 0x80); uint8_t v = SPI.transfer(0);
  digitalWrite(PIN_ADXL_CS, HIGH); SPI.endTransaction();
  return v;
}
static void adxlWrite(uint8_t reg, uint8_t v) {
  SPI.beginTransaction(ADXL_SPI); digitalWrite(PIN_ADXL_CS, LOW);
  SPI.transfer(reg & 0x3F); SPI.transfer(v);
  digitalWrite(PIN_ADXL_CS, HIGH); SPI.endTransaction();
}
static void adxlBurst(int16_t *x, int16_t *y, int16_t *z) {
  uint8_t b[6];
  SPI.beginTransaction(ADXL_SPI); digitalWrite(PIN_ADXL_CS, LOW);
  SPI.transfer(0x32 | 0x80 | 0x40);
  for (int i = 0; i < 6; i++) b[i] = SPI.transfer(0);
  digitalWrite(PIN_ADXL_CS, HIGH); SPI.endTransaction();
  *x = (int16_t)(b[0] | (b[1] << 8));
  *y = (int16_t)(b[2] | (b[3] << 8));
  *z = (int16_t)(b[4] | (b[5] << 8));
}
static bool adxlInit() {
  pinMode(PIN_ADXL_CS, OUTPUT); digitalWrite(PIN_ADXL_CS, HIGH);
  pinMode(PIN_ADXL_INT1, INPUT);
  if (adxlRead(0x00) != 0xE5) return false;
  adxlWrite(0x2D, 0x00);              // standby while configuring
  adxlWrite(0x31, 0x0B);              // full resolution, 4-wire SPI, +/-200 g
  adxlWrite(0x2C, ADXL_BW_RATE_REG);  // output data rate
  adxlWrite(0x38, 0x9F);              // FIFO stream mode
  adxlWrite(0x2E, 0x00);              // no interrupts
  adxlWrite(0x2D, 0x08);              // measure
  return true;
}

// ---------------- LSM6DS3, direct I2C on the internal bus ----------------
const uint8_t IMU_ADDR = 0x6A;
static bool imuWrite(uint8_t reg, uint8_t v) {
  Wire1.beginTransmission(IMU_ADDR); Wire1.write(reg); Wire1.write(v);
  return Wire1.endTransmission() == 0;
}
static bool imuRead(uint8_t reg, uint8_t *buf, uint8_t n) {
  Wire1.beginTransmission(IMU_ADDR); Wire1.write(reg);
  if (Wire1.endTransmission(false) != 0) return false;
  if (Wire1.requestFrom(IMU_ADDR, n) != n) return false;
  for (uint8_t i = 0; i < n; i++) buf[i] = Wire1.read();
  return true;
}
static bool imuInit() {
  // The Sense Plus needs its IMU supply pin in high-drive mode, or the
  // IMU never powers up (measured 2026-09-13, see docs/mk2_build.md).
  pinMode(PIN_LSM6DS3TR_C_POWER, OUTPUT_H0H1);
  digitalWrite(PIN_LSM6DS3TR_C_POWER, HIGH);
  delay(50);
  // The nRF52 Wire driver hangs forever on a bus held low. Check first.
  pinMode(PIN_WIRE1_SDA, INPUT_PULLUP); pinMode(PIN_WIRE1_SCL, INPUT_PULLUP); delayMicroseconds(200);
  if (!digitalRead(PIN_WIRE1_SDA) || !digitalRead(PIN_WIRE1_SCL)) return false;
  Wire1.begin();
  Wire1.setClock(400000);
  uint8_t who = 0;
  if (!imuRead(0x0F, &who, 1) || (who != 0x6A && who != 0x69)) return false;
  imuWrite(0x12, 0x44);   // CTRL3_C: block data update, auto-increment
  imuWrite(0x10, 0x44);   // CTRL1_XL: 104 Hz, +/-16 g
  imuWrite(0x11, 0x4C);   // CTRL2_G: 104 Hz, 2000 dps
  return true;
}
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

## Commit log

2026-08-24 Add HTML ride reports and track raw SD card logs
2026-08-24 Tune datalogger firmware from live hardware testing
    - Bump accel range to 16G to stop clipping on hard hits
    - Show shred scores of 10g+ as whole numbers, since the display can't
    fit an extra digit alongside the decimal
    - Keep the SD file open for the whole run instead of reopening it
    every sample, flushing every 15 samples instead
    - Raise serial baud rate to 115200
    - Fix a doubled line ending that left a blank line after every row
    [Shredometer_Datalogger.ino]
2026-08-25 Drop per-sample serial echo, document hardware and firmware changes
    The Nano Every echo of every logged line over serial cost loop time
    and nothing read it live at 100+ Hz. README now reflects the actual
    board (Nano Every, not classic Nano) and the recent firmware tuning.
2026-08-29 Add bottle cage mount CAD and print test files
    [bottle_cage_mount.scad, cage_full_REFERENCE_ONLY.stl, cradle_bottom_test.stl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]
2026-09-12 Add DL_61 log and report, oversampling firmware, and v2 cradle with lid
    [bottle_cage_mount.scad, cage_full_REFERENCE_ONLY.stl, cradle_bottom_test.stl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]
2026-09-12 Document the Mk2 rebuild plan and BOM
    [bottle_cage_mount.scad]
2026-09-12 Bench log: ADXL375 soldered and clean; note the noise floor
    [Shredometer_Mk2_Bringup.ino]
2026-09-13 Sense Plus IMU: power pin needs high drive
2026-09-13 microSD passes: power its 3V pin; log SD timing and the MISO pull-down trap
2026-09-13 Bench log: display passes at 3.3 V with 10k pull-ups
2026-09-13 Display LED current corrupts the ADXL375: boost converter is now required
2026-09-13 Add Mk2 logger firmware and binary-to-CSV converter
    Direct SPI/I2C drivers for the ADXL375 (FIFO-drained) and LSM6DS3, a
    binary log format, and scripts/mk2_to_csv.py to feed the existing
    analysis pipeline unchanged. Verified against a synthetic log; not yet
    run on the perfboard.
    Claude-Session: https://claude.ai/code/session_01ABTsnmWMng8mW2dGaQmb2Q
2026-09-14 Fix switch net: battery line only, not GND; link the perfboard layout diagram
    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
